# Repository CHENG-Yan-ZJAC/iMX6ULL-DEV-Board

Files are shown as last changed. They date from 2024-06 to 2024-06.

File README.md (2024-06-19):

# iMX6ULL-DEV-Board

iMX6ULL-DEV-Board is a development board based on NXP i.MX6ULL. It is composed of core board and carrier board. The boards were developed in KiCad 8.0.

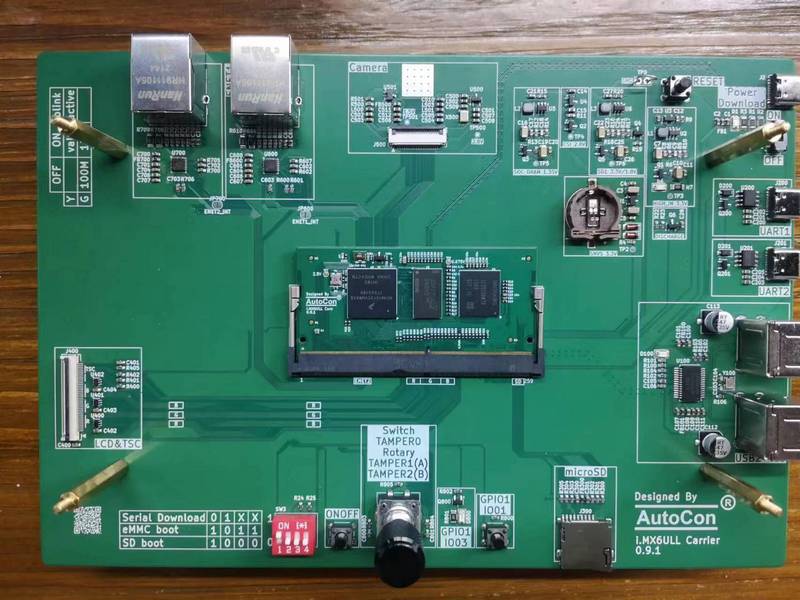
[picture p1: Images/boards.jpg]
DEV Board


## Core Board
* i.MX6ULL, MCIMX6Y2CVM08AB, ARM Cortex-A7, 798MHz.
* Samsung, KLM8G1GETF-B041, 8GB eMMC.
* Micro, MT41K256M16, DDR3L, 512MB.
* DDR4 edge connector.

## Carrier Board
* micro SD x 1, 4-bit width.
* LCD.
* CSI.
* UART1, UART2.
* USB1: used as power and flash the eMMC.
* USB2: expand to 4 USB Type-A by USB Hub (GENESYS GL850G-HHY22).
* ENET1, ENET2: PHY SMSC LAN8720A-CP-TR.
* GPIO.

## How to use
* Connect the J2 (upright corner marked "Power Download") to 5V by a Type-C line.
* Connect the Type-C (the 2nd Type-C connector marked "UART1") to PC, it is the console.
* Insert micro SD to slot (downright corner marked "micro SD").
* Set the code switch to 1 0 0 0, boot from micro SD.
* Swith on (upright corner marked "ON OFF").

## Contact:
Feel free to contact me yan.cheng@hnautocontrol.com.

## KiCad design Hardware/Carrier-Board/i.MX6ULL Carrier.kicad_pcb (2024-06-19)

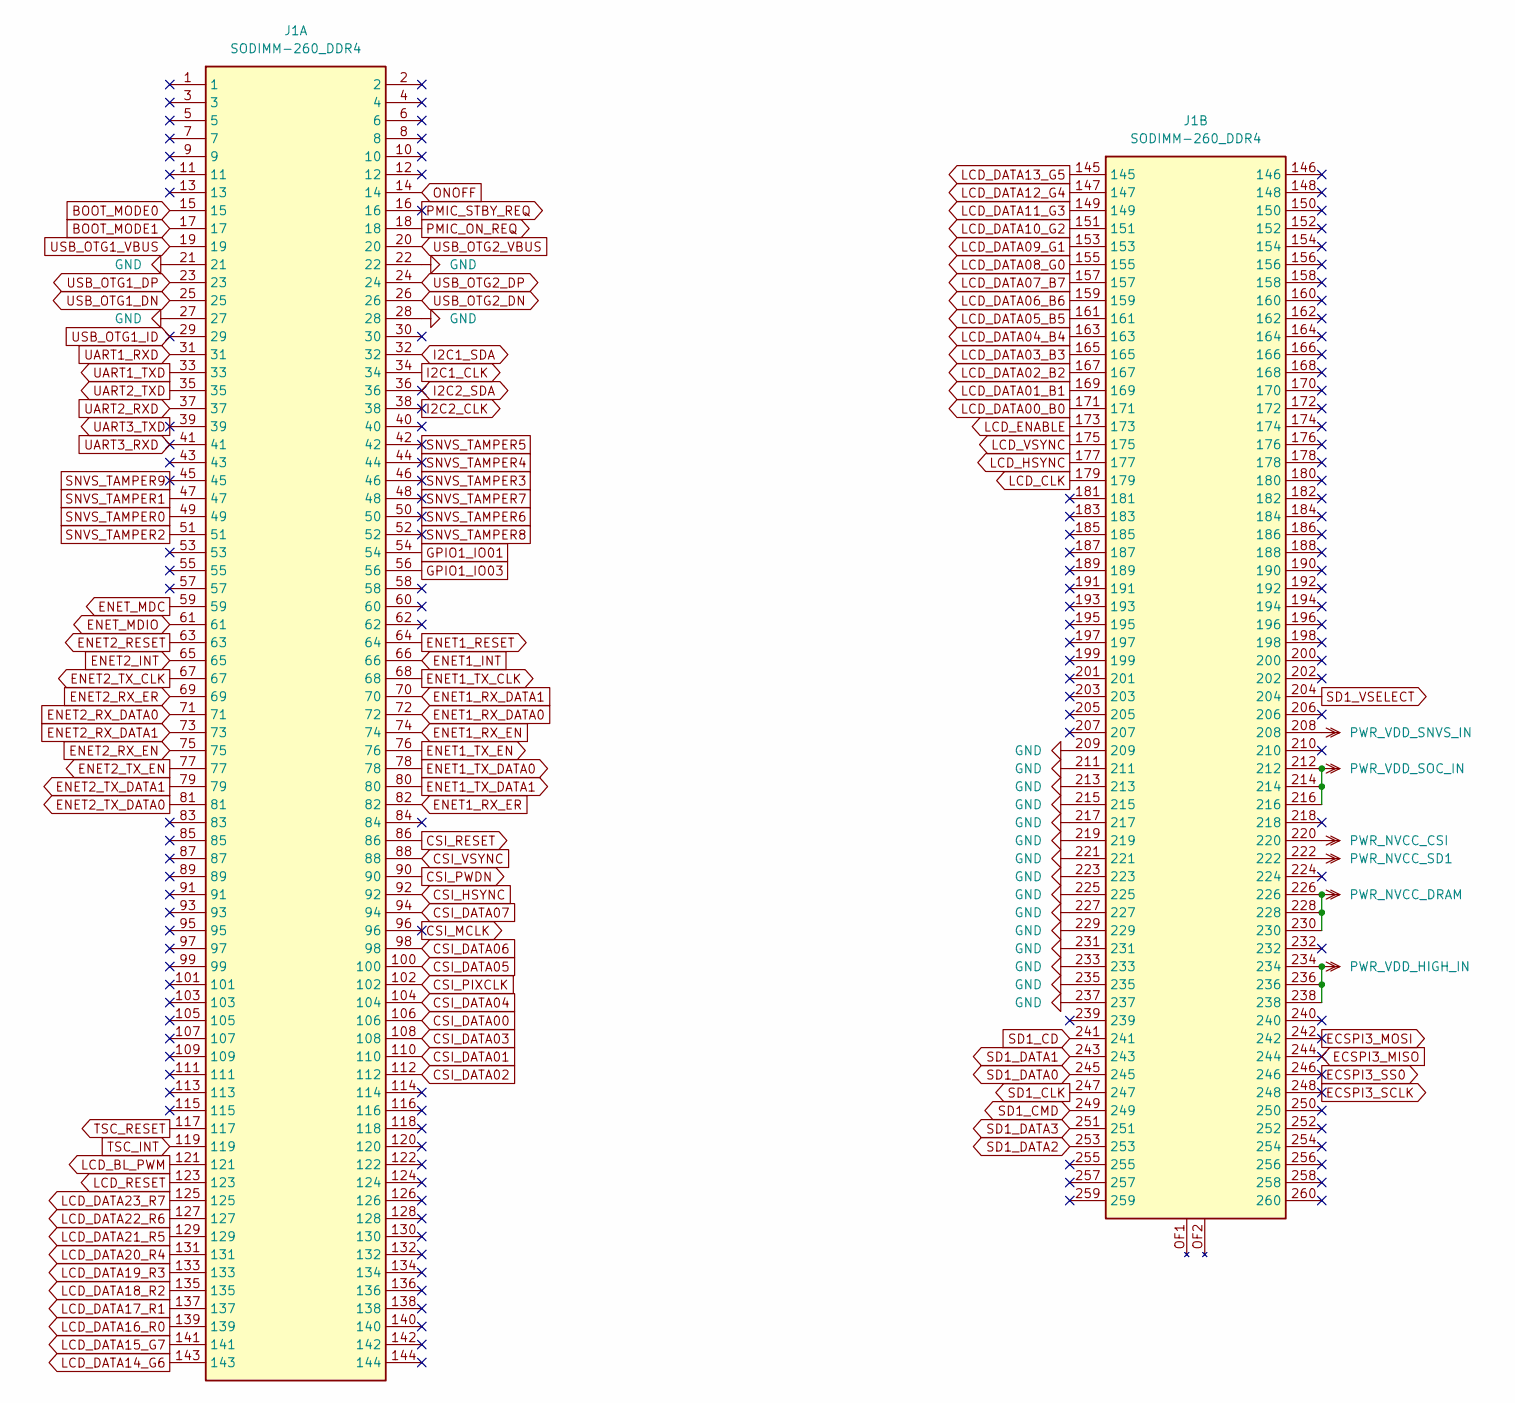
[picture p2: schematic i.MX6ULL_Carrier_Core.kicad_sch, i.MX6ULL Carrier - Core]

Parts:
J1: SODIMM-260_DDR4; SODIMM-260_DDR4_Card_slot

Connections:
BOOT_MODE0: J1.15; also elsewhere on the board
BOOT_MODE1: J1.17; also elsewhere on the board
CSI_DATA00: J1.106; also elsewhere on the board
CSI_DATA01: J1.110; also elsewhere on the board
CSI_DATA02: J1.112; also elsewhere on the board
CSI_DATA03: J1.108; also elsewhere on the board
CSI_DATA04: J1.104; also elsewhere on the board
CSI_DATA05: J1.100; also elsewhere on the board
CSI_DATA06: J1.98; also elsewhere on the board
CSI_DATA07: J1.94; also elsewhere on the board
CSI_HSYNC: J1.92; also elsewhere on the board
CSI_MCLK: J1.96
CSI_PIXCLK: J1.102; also elsewhere on the board
CSI_PWDN: J1.90; also elsewhere on the board
CSI_RESET: J1.86; also elsewhere on the board
CSI_VSYNC: J1.88; also elsewhere on the board
ECSPI3_MISO: J1.244
ECSPI3_MOSI: J1.242
ECSPI3_SCLK: J1.248
ECSPI3_SS0: J1.246
ENET1_INT: J1.66; also elsewhere on the board
ENET1_RESET: J1.64; also elsewhere on the board
ENET1_RX_DATA0: J1.72; also elsewhere on the board
ENET1_RX_DATA1: J1.70; also elsewhere on the board
ENET1_RX_EN: J1.74; also elsewhere on the board
ENET1_RX_ER: J1.82; also elsewhere on the board
ENET1_TX_CLK: J1.68; also elsewhere on the board
ENET1_TX_DATA0: J1.78; also elsewhere on the board
ENET1_TX_DATA1: J1.80; also elsewhere on the board
ENET1_TX_EN: J1.76; also elsewhere on the board
ENET2_INT: J1.65; also elsewhere on the board
ENET2_RESET: J1.63; also elsewhere on the board
ENET2_RX_DATA0: J1.71; also elsewhere on the board
ENET2_RX_DATA1: J1.73; also elsewhere on the board
ENET2_RX_EN: J1.75; also elsewhere on the board
ENET2_RX_ER: J1.69; also elsewhere on the board
ENET2_TX_CLK: J1.67; also elsewhere on the board
ENET2_TX_DATA0: J1.81; also elsewhere on the board
ENET2_TX_DATA1: J1.79; also elsewhere on the board
ENET2_TX_EN: J1.77; also elsewhere on the board
ENET_MDC: J1.59; also elsewhere on the board
ENET_MDIO: J1.61; also elsewhere on the board
GND: J1.21, J1.22, J1.27, J1.28, J1.209, J1.211, J1.213, J1.215, J1.217, J1.219, J1.221, J1.223, J1.225, J1.227, J1.229, J1.231, J1.233, J1.235, J1.237; also elsewhere on the board
GPIO1_IO01: J1.54; also elsewhere on the board
GPIO1_IO03: J1.56; also elsewhere on the board
I2C1_CLK: J1.34; also elsewhere on the board
I2C1_SDA: J1.32; also elsewhere on the board
I2C2_CLK: J1.38
I2C2_SDA: J1.36
LCD_BL_PWM: J1.121; also elsewhere on the board
LCD_CLK: J1.179; also elsewhere on the board
LCD_DATA00_B0: J1.171; also elsewhere on the board
LCD_DATA01_B1: J1.169; also elsewhere on the board
LCD_DATA02_B2: J1.167; also elsewhere on the board
LCD_DATA03_B3: J1.165; also elsewhere on the board
LCD_DATA04_B4: J1.163; also elsewhere on the board
LCD_DATA05_B5: J1.161; also elsewhere on the board
LCD_DATA06_B6: J1.159; also elsewhere on the board
LCD_DATA07_B7: J1.157; also elsewhere on the board
LCD_DATA08_G0: J1.155; also elsewhere on the board
LCD_DATA09_G1: J1.153; also elsewhere on the board
LCD_DATA10_G2: J1.151; also elsewhere on the board
LCD_DATA11_G3: J1.149; also elsewhere on the board
LCD_DATA12_G4: J1.147; also elsewhere on the board
LCD_DATA13_G5: J1.145; also elsewhere on the board
LCD_DATA14_G6: J1.143; also elsewhere on the board
LCD_DATA15_G7: J1.141; also elsewhere on the board
LCD_DATA16_R0: J1.139; also elsewhere on the board
LCD_DATA17_R1: J1.137; also elsewhere on the board
LCD_DATA18_R2: J1.135; also elsewhere on the board
LCD_DATA19_R3: J1.133; also elsewhere on the board
LCD_DATA20_R4: J1.131; also elsewhere on the board
LCD_DATA21_R5: J1.129; also elsewhere on the board
LCD_DATA22_R6: J1.127; also elsewhere on the board
LCD_DATA23_R7: J1.125; also elsewhere on the board
LCD_ENABLE: J1.173; also elsewhere on the board
LCD_HSYNC: J1.177; also elsewhere on the board
LCD_RESET: J1.123; also elsewhere on the board
LCD_VSYNC: J1.175; also elsewhere on the board
ONOFF: J1.14; also elsewhere on the board
PMIC_ON_REQ: J1.18; also elsewhere on the board
PMIC_STBY_REQ: J1.16
PWR_NVCC_CSI: J1.220; also elsewhere on the board
PWR_NVCC_DRAM: J1.212, J1.214, J1.216, J1.226, J1.228, J1.230; also elsewhere on the board
PWR_NVCC_SD1: J1.222; also elsewhere on the board
PWR_VDD_HIGH_IN: J1.234, J1.236, J1.238; also elsewhere on the board
PWR_VDD_SNVS_IN: J1.208; also elsewhere on the board
SD1_CD: J1.241; also elsewhere on the board
SD1_CLK: J1.247; also elsewhere on the board
SD1_CMD: J1.249; also elsewhere on the board
SD1_DATA0: J1.245; also elsewhere on the board
SD1_DATA1: J1.243; also elsewhere on the board
SD1_DATA2: J1.253; also elsewhere on the board
SD1_DATA3: J1.251; also elsewhere on the board
SD1_VSELECT: J1.204; also elsewhere on the board
SNVS_TAMPER0: J1.49; also elsewhere on the board
SNVS_TAMPER1: J1.47; also elsewhere on the board
SNVS_TAMPER2: J1.51; also elsewhere on the board
SNVS_TAMPER3: J1.46
SNVS_TAMPER4: J1.44
SNVS_TAMPER5: J1.42
SNVS_TAMPER6: J1.50
SNVS_TAMPER7: J1.48
SNVS_TAMPER8: J1.52
SNVS_TAMPER9: J1.45
TSC_INT: J1.119; also elsewhere on the board
TSC_RESET: J1.117; also elsewhere on the board
UART1_RXD: J1.31; also elsewhere on the board
UART1_TXD: J1.33; also elsewhere on the board
UART2_RXD: J1.37; also elsewhere on the board
UART2_TXD: J1.35; also elsewhere on the board
UART3_RXD: J1.41
UART3_TXD: J1.39
USB_OTG1_DN: J1.25; also elsewhere on the board
USB_OTG1_DP: J1.23; also elsewhere on the board
USB_OTG1_ID: J1.29
USB_OTG1_VBUS: J1.19; also elsewhere on the board
USB_OTG2_DN: J1.26; also elsewhere on the board
USB_OTG2_DP: J1.24; also elsewhere on the board
USB_OTG2_VBUS: J1.20; also elsewhere on the board

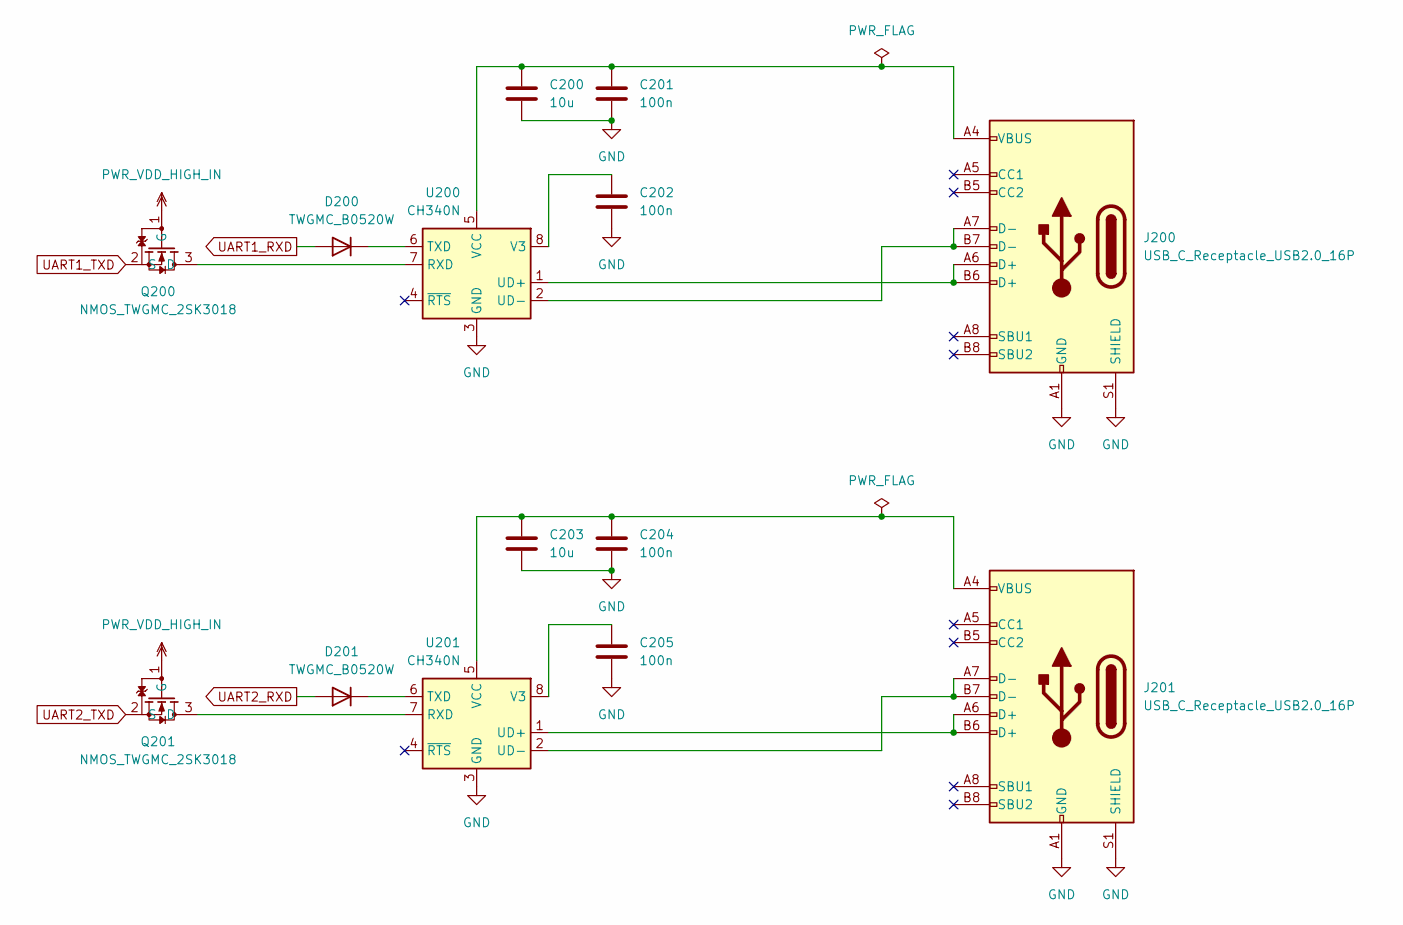
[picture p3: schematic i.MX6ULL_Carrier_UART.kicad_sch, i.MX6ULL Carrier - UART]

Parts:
C200, C203: 10u; C_0603_1608Metric
C201, C202, C204, C205: 100n; C_0603_1608Metric
D200, D201: TWGMC_B0520W; D_SOD-123
J200, J201: USB_C_Receptacle_USB2.0_16P; USB_C_Receptacle_G-Switch_GT-USB-7010ASV
Q200, Q201: NMOS_TWGMC_2SK3018; SOT-23-3
U200, U201: CH340N; SOP-8_3.9x4.9mm_P1.27mm

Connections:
GND: C200.2, C201.2, C202.2, C203.2, C204.2, C205.2, J200.A1 (GND), J200.A12 (GND), J200.B1 (GND), J200.B12 (GND), J200.S1 (SHIELD), J201.A1 (GND), J201.A12 (GND), J201.B1 (GND), J201.B12 (GND), J201.S1 (SHIELD), U200.3 (GND), U201.3 (GND); also elsewhere on the board
unnamed: D200.1 (K), U200.6 (TXD)
unnamed: D201.1 (K), U201.6 (TXD)
unnamed: Q200.3 (D), U200.7 (RXD)
unnamed: Q201.3 (D), U201.7 (RXD)
unnamed: J200.A6 (D+), J200.B6 (D+), U200.1 (UD+)
unnamed: J200.A7 (D-), J200.B7 (D-), U200.2 (UD-)
unnamed: C202.1, U200.8 (V3)
unnamed: C200.1, C201.1, J200.A4 (VBUS), J200.A9 (VBUS), J200.B4 (VBUS), J200.B9 (VBUS), U200.5 (VCC)
unnamed: J201.A6 (D+), J201.B6 (D+), U201.1 (UD+)
unnamed: J201.A7 (D-), J201.B7 (D-), U201.2 (UD-)
unnamed: C205.1, U201.8 (V3)
unnamed: C203.1, C204.1, J201.A4 (VBUS), J201.A9 (VBUS), J201.B4 (VBUS), J201.B9 (VBUS), U201.5 (VCC)
PWR_VDD_HIGH_IN: Q200.1 (G), Q201.1 (G); also elsewhere on the board
UART1_RXD: D200.2 (A); also elsewhere on the board
UART1_TXD: Q200.2 (S); also elsewhere on the board
UART2_RXD: D201.2 (A); also elsewhere on the board
UART2_TXD: Q201.2 (S); also elsewhere on the board

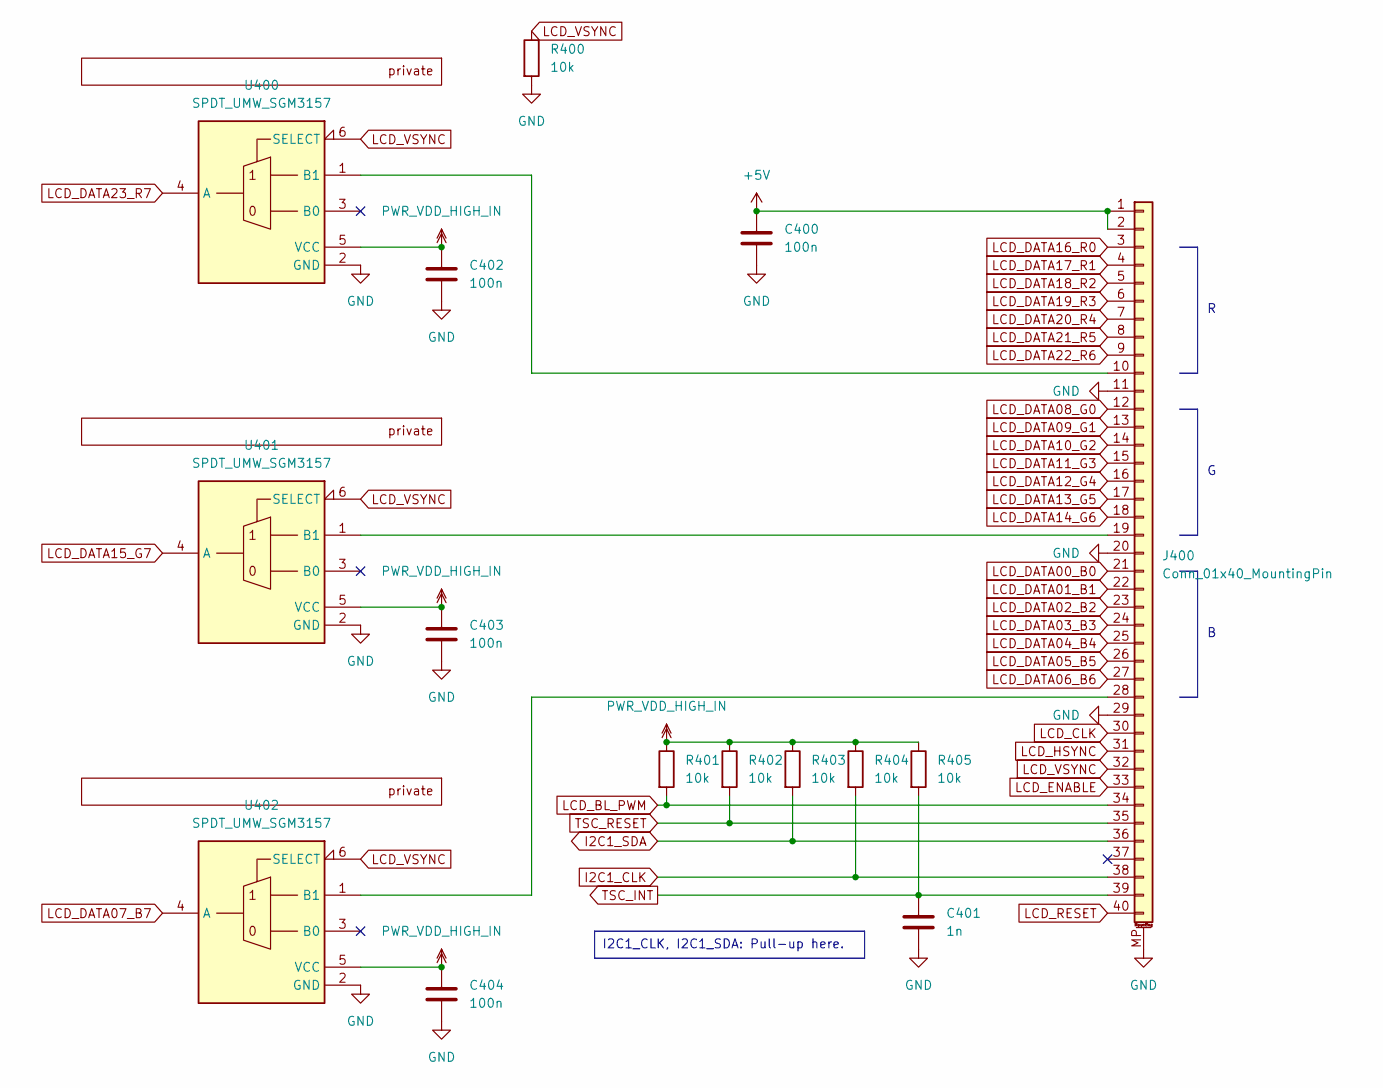
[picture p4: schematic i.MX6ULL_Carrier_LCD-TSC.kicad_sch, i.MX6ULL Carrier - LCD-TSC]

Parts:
C400, C402, C403, C404: 100n; C_0603_1608Metric
C401: 1n; C_0603_1608Metric
J400: Conn_01x40_MountingPin; Connector_FPC_1x40-1MP_P0.05mm
R400, R401, R402, R403, R404, R405: 10k; R_0603_1608Metric
U400, U401, U402: SPDT_UMW_SGM3157; SOT-363_SC-70-6

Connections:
+5V: C400.1, J400.1, J400.2; also elsewhere on the board
GND: C400.2, C401.2, C402.2, C403.2, C404.2, J400.11, J400.20, J400.29, J400.MP (MountPin), R400.2, U400.2 (GND), U401.2 (GND), U402.2 (GND); also elsewhere on the board
I2C1_CLK: J400.38, R404.2; also elsewhere on the board
I2C1_SDA: J400.36, R403.2; also elsewhere on the board
LCD_BL_PWM: J400.34, R401.2; also elsewhere on the board
LCD_CLK: J400.30; also elsewhere on the board
LCD_DATA00_B0: J400.21; also elsewhere on the board
LCD_DATA01_B1: J400.22; also elsewhere on the board
LCD_DATA02_B2: J400.23; also elsewhere on the board
LCD_DATA03_B3: J400.24; also elsewhere on the board
LCD_DATA04_B4: J400.25; also elsewhere on the board
LCD_DATA05_B5: J400.26; also elsewhere on the board
LCD_DATA06_B6: J400.27; also elsewhere on the board
LCD_DATA07_B7: U402.4 (A); also elsewhere on the board
LCD_DATA08_G0: J400.12; also elsewhere on the board
LCD_DATA09_G1: J400.13; also elsewhere on the board
LCD_DATA10_G2: J400.14; also elsewhere on the board
LCD_DATA11_G3: J400.15; also elsewhere on the board
LCD_DATA12_G4: J400.16; also elsewhere on the board
LCD_DATA13_G5: J400.17; also elsewhere on the board
LCD_DATA14_G6: J400.18; also elsewhere on the board
LCD_DATA15_G7: U401.4 (A); also elsewhere on the board
LCD_DATA16_R0: J400.3; also elsewhere on the board
LCD_DATA17_R1: J400.4; also elsewhere on the board
LCD_DATA18_R2: J400.5; also elsewhere on the board
LCD_DATA19_R3: J400.6; also elsewhere on the board
LCD_DATA20_R4: J400.7; also elsewhere on the board
LCD_DATA21_R5: J400.8; also elsewhere on the board
LCD_DATA22_R6: J400.9; also elsewhere on the board
LCD_DATA23_R7: U400.4 (A); also elsewhere on the board
LCD_ENABLE: J400.33; also elsewhere on the board
LCD_HSYNC: J400.31; also elsewhere on the board
LCD_RESET: J400.40; also elsewhere on the board
LCD_VSYNC: J400.32, R400.1, U400.6 (SELECT), U401.6 (SELECT), U402.6 (SELECT); also elsewhere on the board
unnamed: J400.10, U400.1 (B1)
unnamed: J400.19, U401.1 (B1)
unnamed: J400.28, U402.1 (B1)
PWR_VDD_HIGH_IN: C402.1, C403.1, C404.1, R401.1, R402.1, R403.1, R404.1, R405.1, U400.5 (VCC), U401.5 (VCC), U402.5 (VCC); also elsewhere on the board
TSC_INT: C401.1, J400.39, R405.2; also elsewhere on the board
TSC_RESET: J400.35, R402.2; also elsewhere on the board

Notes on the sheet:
I2C1_CLK, I2C1_SDA: Pull-up here.

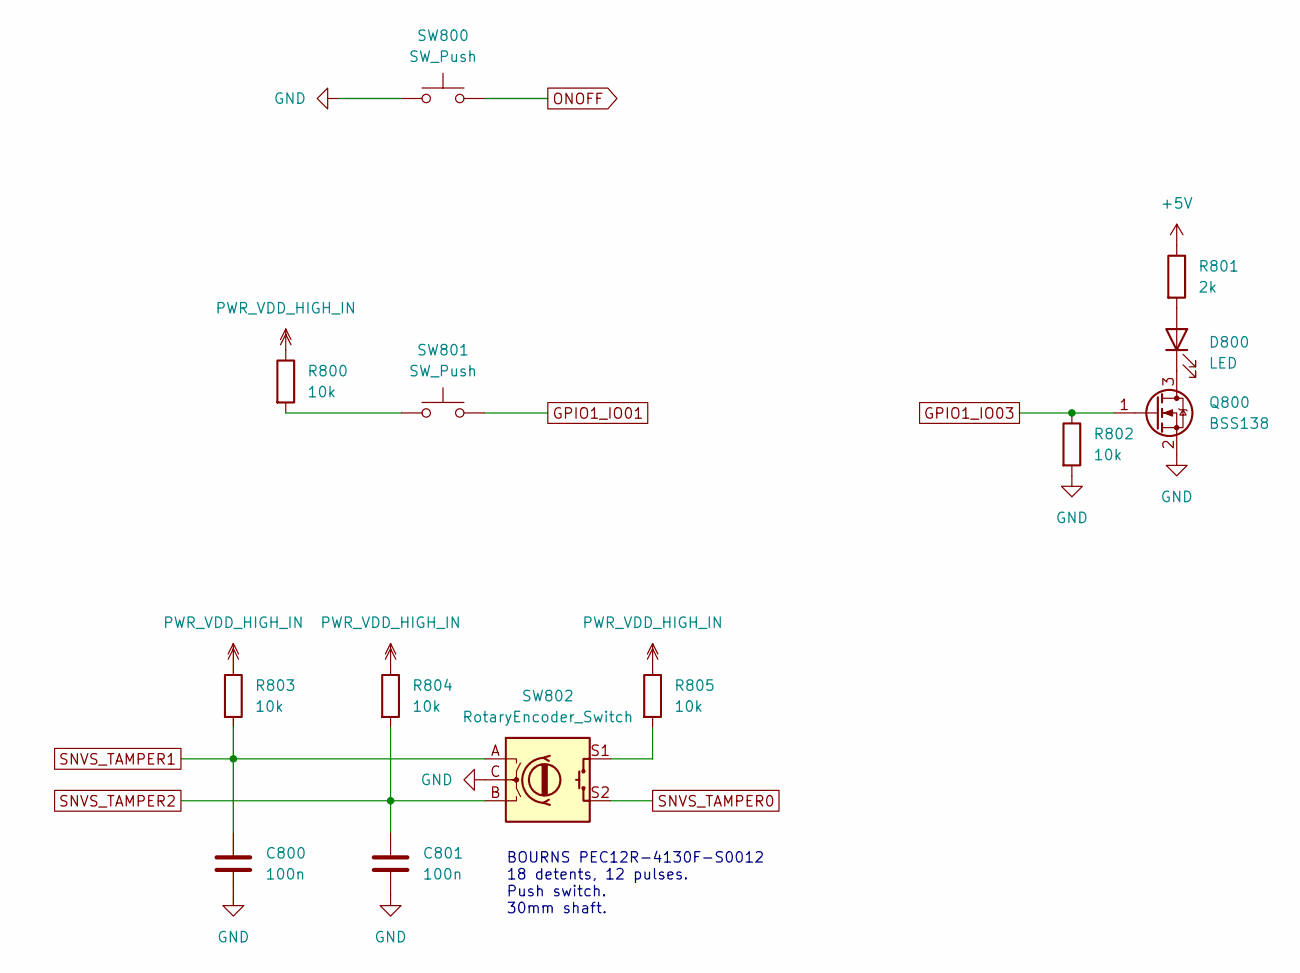
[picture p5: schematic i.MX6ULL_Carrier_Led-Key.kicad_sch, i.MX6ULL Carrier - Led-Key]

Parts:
C800, C801: 100n; C_0603_1608Metric
D800: LED; LED_1206_3216Metric
Q800: BSS138; SOT-23-3
R800, R802, R803, R804, R805: 10k; R_0603_1608Metric
R801: 2k; R_1206_3216Metric
SW800, SW801: SW_Push; SW_PUSH_6mm
SW802: RotaryEncoder_Switch; RotaryEncoder_Bourns_Vertical_PEC12R-3x17F-Sxxxx

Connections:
+5V: R801.1; also elsewhere on the board
GND: C800.2, C801.2, Q800.2 (S), R802.2, SW800.1, SW802.C; also elsewhere on the board
GPIO1_IO01: SW801.2; also elsewhere on the board
GPIO1_IO03: Q800.1 (G), R802.1; also elsewhere on the board
unnamed: D800.2 (A), R801.2
unnamed: D800.1 (K), Q800.3 (D)
unnamed: R800.2, SW801.1
unnamed: R805.2, SW802.S1
ONOFF: SW800.2; also elsewhere on the board
PWR_VDD_HIGH_IN: R800.1, R803.1, R804.1, R805.1; also elsewhere on the board
SNVS_TAMPER0: SW802.S2; also elsewhere on the board
SNVS_TAMPER1: C800.1, R803.2, SW802.A; also elsewhere on the board
SNVS_TAMPER2: C801.1, R804.2, SW802.B; also elsewhere on the board

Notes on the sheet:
BOURNS PEC12R-4130F-S0012 18 detents, 12 pulses. Push switch. 30mm shaft.

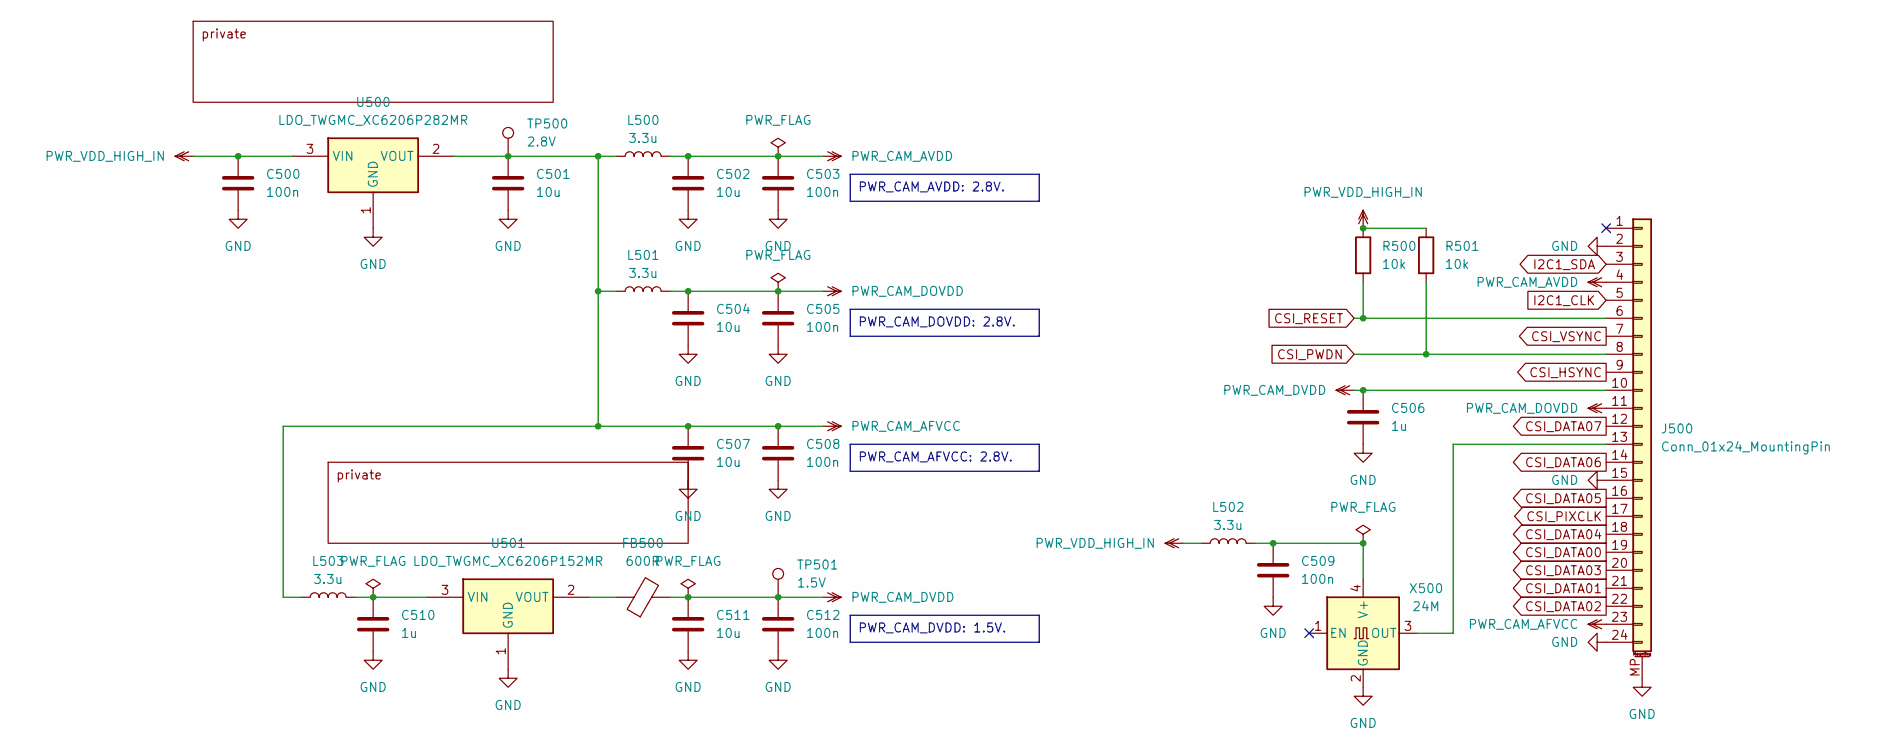
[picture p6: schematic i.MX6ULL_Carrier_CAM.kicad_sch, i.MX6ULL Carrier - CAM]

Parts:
C500, C503, C505, C508, C509, C512: 100n; C_0603_1608Metric
C501, C502, C504, C507, C511: 10u; C_0603_1608Metric
C506, C510: 1u; C_0603_1608Metric
FB500: 600R; L_0603_1608Metric
J500: Conn_01x24_MountingPin; Connector_FPC_1x24-1MP_P0.05mm
L500, L501, L502, L503: 3.3u; L_0603_1608Metric
R500, R501: 10k; R_0603_1608Metric
TP500: 2.8V; TestPoint_Pad_D1.0mm
TP501: 1.5V; TestPoint_Pad_D1.0mm
U500: LDO_TWGMC_XC6206P282MR; SOT-23-3
U501: LDO_TWGMC_XC6206P152MR; SOT-23-3
X500: 24M; Oscillator_SMD_EuroQuartz_XO32-4Pin_3.2x2.5mm

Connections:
CSI_DATA00: J500.19; also elsewhere on the board
CSI_DATA01: J500.21; also elsewhere on the board
CSI_DATA02: J500.22; also elsewhere on the board
CSI_DATA03: J500.20; also elsewhere on the board
CSI_DATA04: J500.18; also elsewhere on the board
CSI_DATA05: J500.16; also elsewhere on the board
CSI_DATA06: J500.14; also elsewhere on the board
CSI_DATA07: J500.12; also elsewhere on the board
CSI_HSYNC: J500.9; also elsewhere on the board
CSI_PIXCLK: J500.17; also elsewhere on the board
CSI_PWDN: J500.8, R501.2; also elsewhere on the board
CSI_RESET: J500.6, R500.2; also elsewhere on the board
CSI_VSYNC: J500.7; also elsewhere on the board
GND: C500.2, C501.2, C502.2, C503.2, C504.2, C505.2, C506.2, C507.2, C508.2, C509.2, C510.2, C511.2, C512.2, J500.2, J500.15, J500.24, J500.MP (MountPin), U500.1 (GND), U501.1 (GND), X500.2 (GND); also elsewhere on the board
I2C1_CLK: J500.5; also elsewhere on the board
I2C1_SDA: J500.3; also elsewhere on the board
unnamed: J500.13, X500.3 (OUT)
unnamed: C510.1, L503.2, U501.3 (VIN)
unnamed: FB500.1, U501.2 (VOUT)
unnamed: C509.1, L502.2, X500.4 (V+)
PWR_CAM_AFVCC: C501.1, C507.1, C508.1, J500.23, L500.1, L501.1, L503.1, TP500.1, U500.2 (VOUT)
PWR_CAM_AVDD: C502.1, C503.1, J500.4, L500.2
PWR_CAM_DOVDD: C504.1, C505.1, J500.11, L501.2
PWR_CAM_DVDD: C506.1, C511.1, C512.1, FB500.2, J500.10, TP501.1
PWR_VDD_HIGH_IN: C500.1, L502.1, R500.1, R501.1, U500.3 (VIN); also elsewhere on the board

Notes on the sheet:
PWR_CAM_DVDD: 1.5V.
PWR_CAM_AFVCC: 2.8V.
PWR_CAM_AVDD: 2.8V.
PWR_CAM_DOVDD: 2.8V.

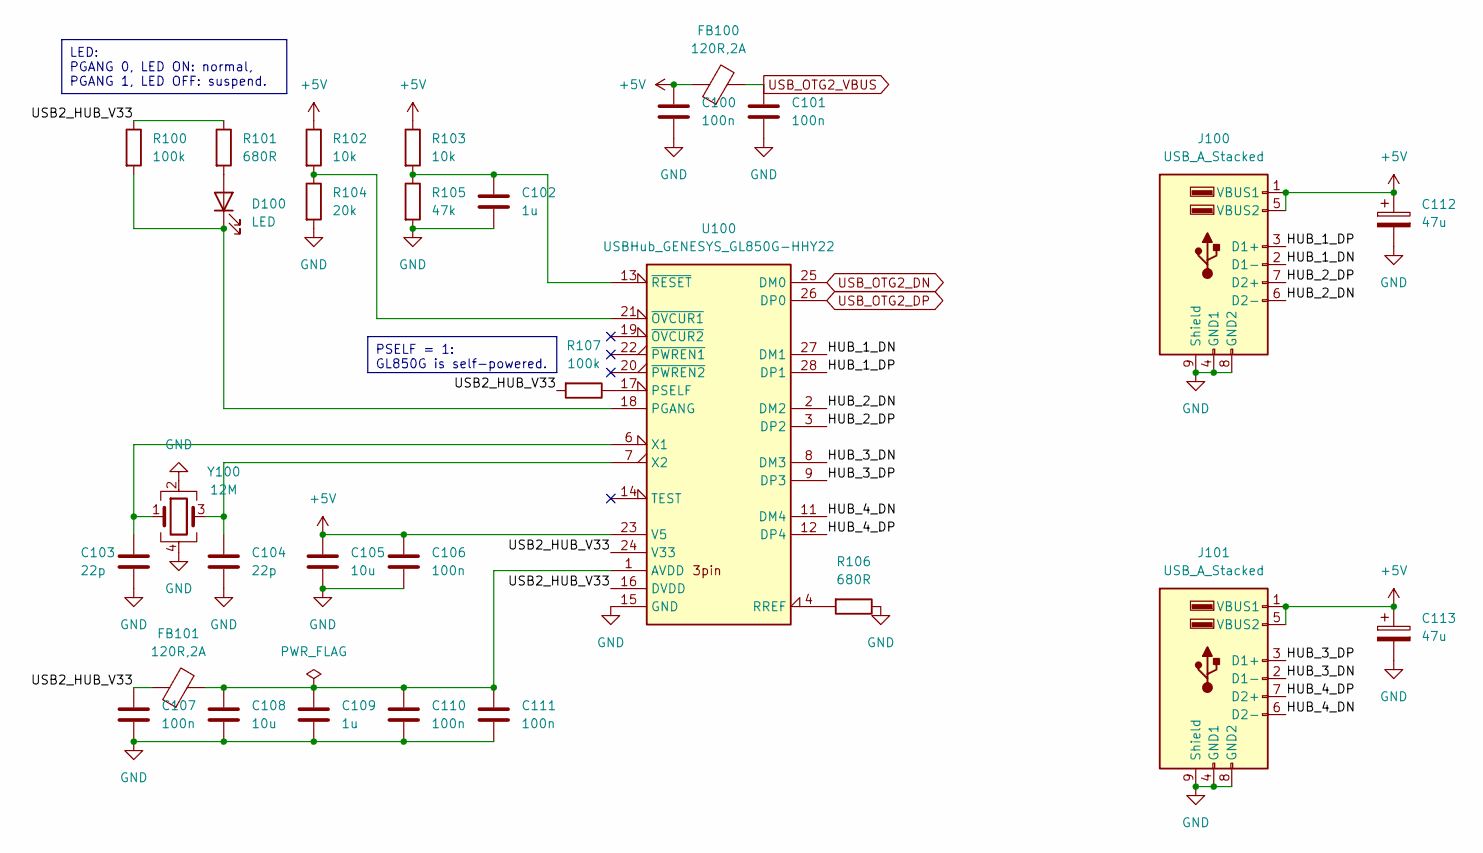
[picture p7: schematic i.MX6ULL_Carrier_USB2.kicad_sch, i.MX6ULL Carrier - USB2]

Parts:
C100, C101, C106, C107, C110, C111: 100n; C_0603_1608Metric
C102, C109: 1u; C_0603_1608Metric
C103, C104: 22p; C_0603_1608Metric
C105, C108: 10u; C_0603_1608Metric
C112, C113: 47u; CP_Elec_6.3x5.4
D100: LED; LED_1206_3216Metric
FB100, FB101: 120R,2A; L_0603_1608Metric
J100, J101: USB_A_Stacked; USB_A_CUI_UJ2-ADH-TH_Horizontal_Stacked
R100, R107: 100k; R_0603_1608Metric
R101, R106: 680R; R_0603_1608Metric
R102, R103: 10k; R_0603_1608Metric
R104: 20k; R_0603_1608Metric
R105: 47k; R_0603_1608Metric
U100: USBHub_GENESYS_GL850G-HHY22; SSOP-28_5.3x10.2mm_P0.65mm
Y100: 12M; Crystal_SMD_3225-4Pin_3.2x2.5mm

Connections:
+5V: C100.1, C105.1, C106.1, C112.1, C113.1, FB100.1, J100.1 (VBUS1), J100.5 (VBUS2), J101.1 (VBUS1), J101.5 (VBUS2), R102.1, R103.1, U100.23 (V5); also elsewhere on the board
/USB2/HUB_1_DN: J100.2 (D1-), U100.27 (DM1)
/USB2/HUB_1_DP: J100.3 (D1+), U100.28 (DP1)
/USB2/HUB_2_DN: J100.6 (D2-), U100.2 (DM2)
/USB2/HUB_2_DP: J100.7 (D2+), U100.3 (DP2)
/USB2/HUB_3_DN: J101.2 (D1-), U100.8 (DM3)
/USB2/HUB_3_DP: J101.3 (D1+), U100.9 (DP3)
/USB2/HUB_4_DN: J101.6 (D2-), U100.11 (DM4)
/USB2/HUB_4_DP: J101.7 (D2+), U100.12 (DP4)
/USB2/USB2_HUB_V33: C107.1, FB101.1, R100.1, R101.1, R107.2, U100.16 (DVDD), U100.24 (V33)
GND: C100.2, C101.2, C102.2, C103.2, C104.2, C105.2, C106.2, C107.2, C108.2, C109.2, C110.2, C111.2, C112.2, C113.2, J100.4 (GND1), J100.8 (GND2), J100.9 (Shield), J101.4 (GND1), J101.8 (GND2), J101.9 (Shield), R104.2, R105.2, R106.1, U100.15 (GND), Y100.2, Y100.4; also elsewhere on the board
unnamed: C108.1, C109.1, C110.1, C111.1, FB101.2, U100.1 (AVDD), U100.5 (AVDD), U100.10 (AVDD)
unnamed: D100.2 (A), R101.2
unnamed: D100.1 (K), R100.2, U100.18 (PGANG)
unnamed: R107.1, U100.17 (PSELF)
unnamed: R106.2, U100.4 (RREF)
unnamed: C103.1, U100.6 (X1), Y100.1
unnamed: C104.1, U100.7 (X2), Y100.3
unnamed: R102.2, R104.1, U100.21 (~OVCUR1)
unnamed: C102.1, R103.2, R105.1, U100.13 (~RESET)
USB_OTG2_DN: U100.25 (DM0); also elsewhere on the board
USB_OTG2_DP: U100.26 (DP0); also elsewhere on the board
USB_OTG2_VBUS: C101.1, FB100.2; also elsewhere on the board

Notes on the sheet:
PSELF = 1: GL850G is self-powered.
LED: PGANG 0, LED ON: normal, PGANG 1, LED OFF: suspend.

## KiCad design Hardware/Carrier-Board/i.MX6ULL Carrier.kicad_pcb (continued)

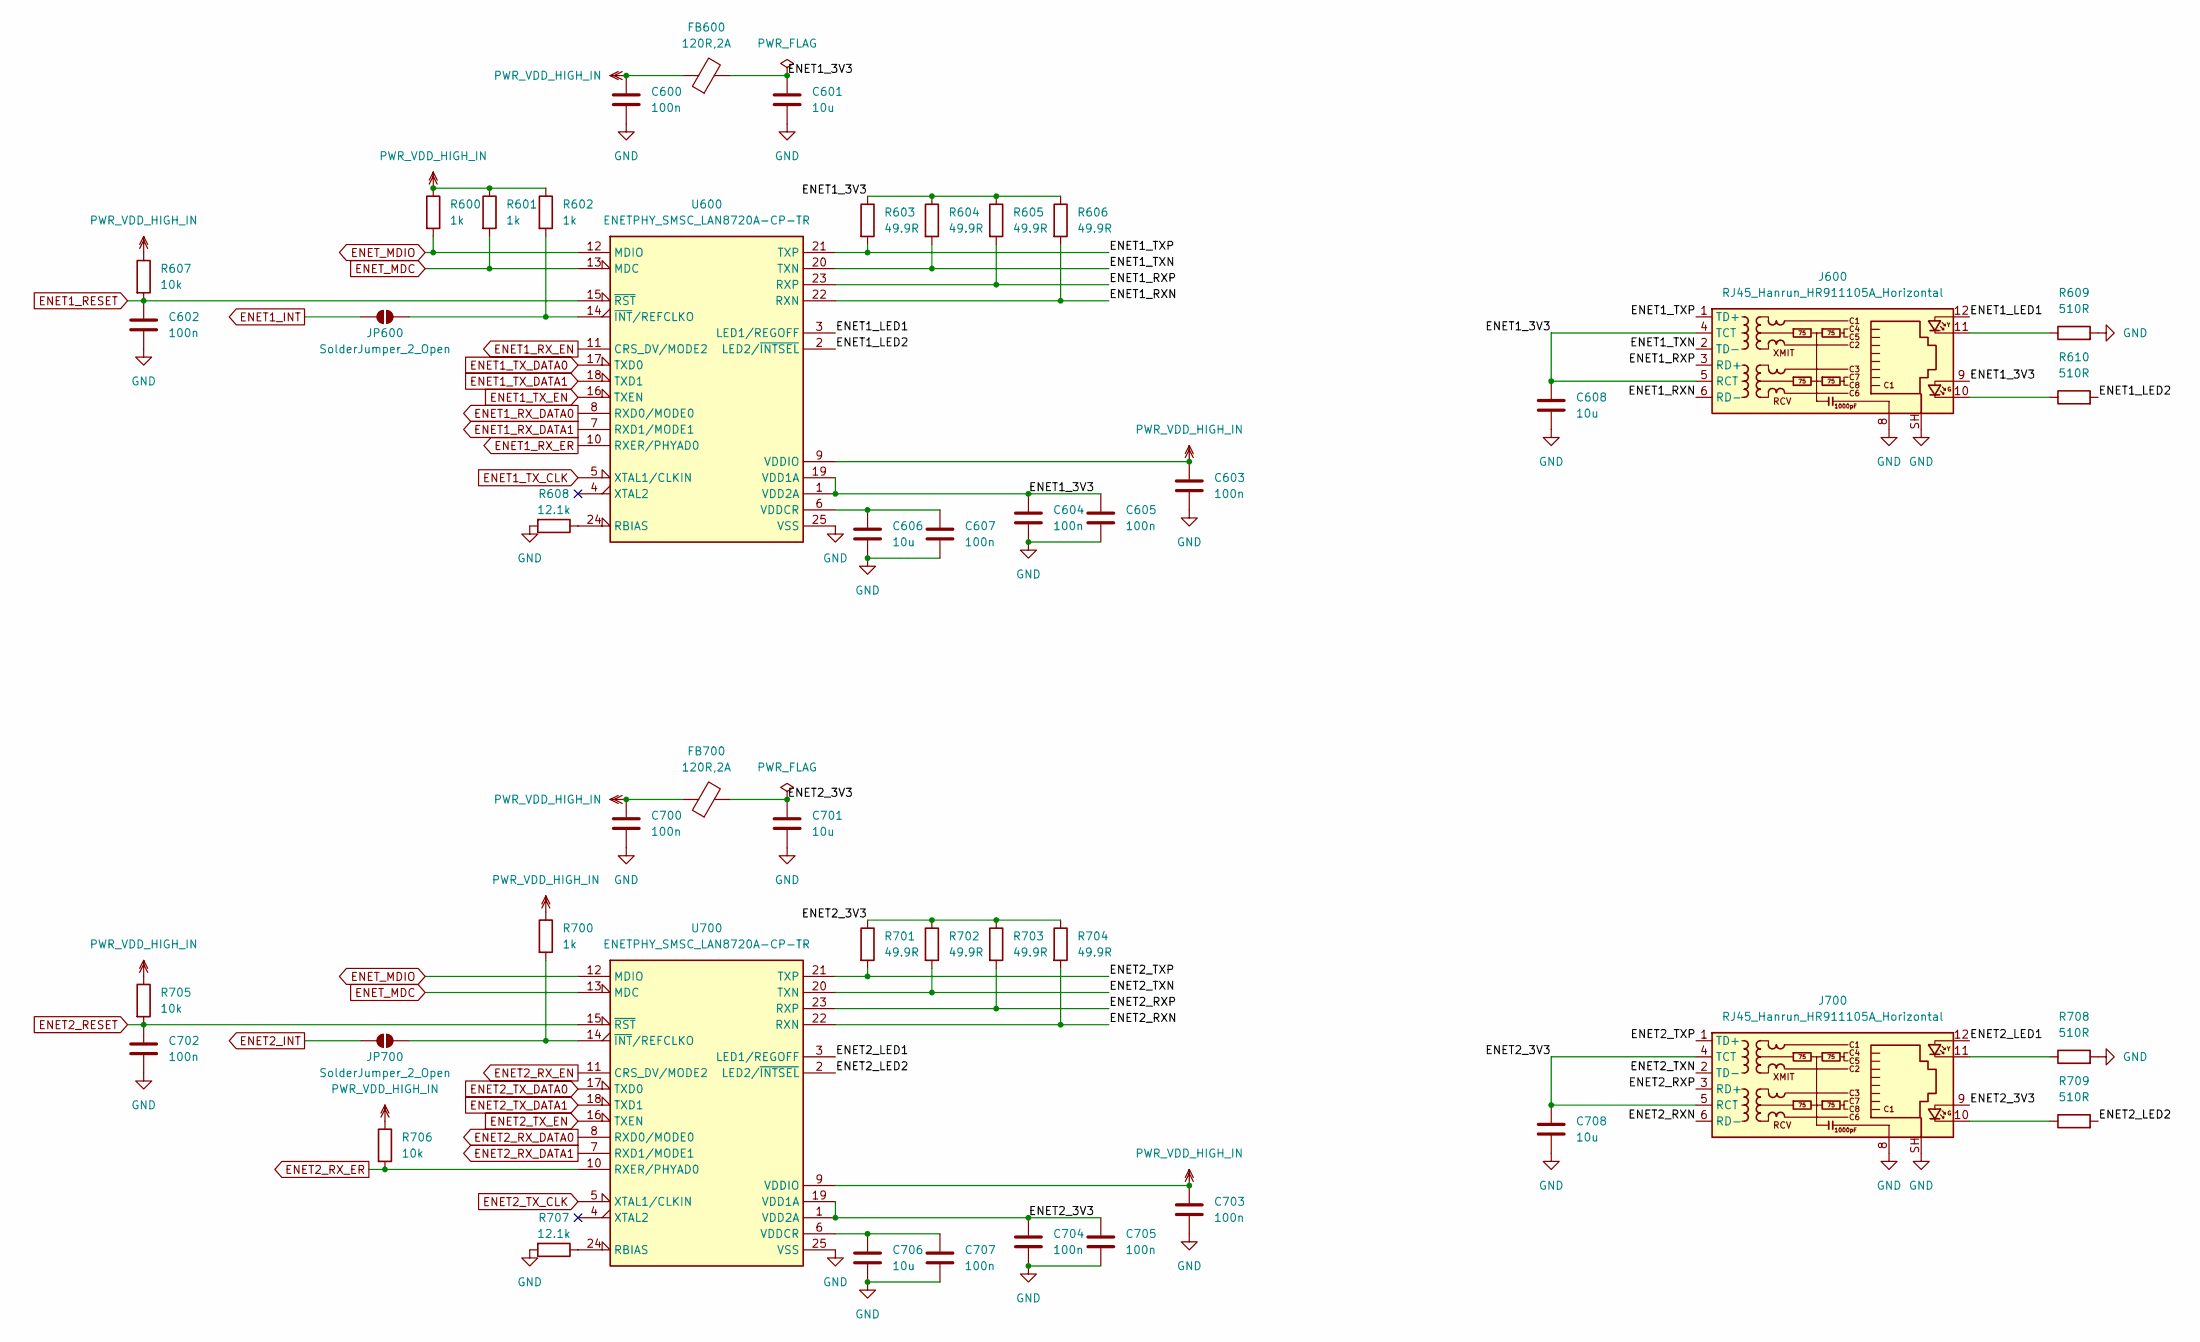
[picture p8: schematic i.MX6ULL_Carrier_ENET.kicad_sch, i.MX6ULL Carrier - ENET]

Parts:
C600, C602, C603, C604, C605, C607, C700, C702, C703, C704, C705, C707: 100n; C_0603_1608Metric
C601, C606, C608, C701, C706, C708: 10u; C_0603_1608Metric
FB600, FB700: 120R,2A; L_0603_1608Metric
J600, J700: RJ45_Hanrun_HR911105A_Horizontal
JP600, JP700: SolderJumper_2_Open; SolderJumper-2_P1.3mm_Open_RoundedPad1.0x1.5mm
R600, R601, R602, R700: 1k; R_0603_1608Metric
R603, R604, R605, R606, R701, R702, R703, R704: 49.9R; R_0603_1608Metric
R607, R705, R706: 10k; R_0603_1608Metric
R608, R707: 12.1k; R_0603_1608Metric
R609, R610, R708, R709: 510R; R_1206_3216Metric
U600, U700: ENETPHY_SMSC_LAN8720A-CP-TR; QFN-24-1EP_4x4mm_P0.5mm_EP2.5x2.5mm

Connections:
/ENET/ENET1_3V3: C601.1, C604.1, C605.1, C608.1, FB600.2, J600.4 (TCT), J600.5 (RCT), J600.9, R603.1, R604.1, R605.1, R606.1, U600.1 (VDD2A), U600.19 (VDD1A)
/ENET/ENET1_LED1: J600.12, U600.3 (LED1/REGOFF)
/ENET/ENET1_LED2: R610.2, U600.2 (LED2/~INTSEL)
/ENET/ENET1_RXN: J600.6 (RD-), R606.2, U600.22 (RXN)
/ENET/ENET1_RXP: J600.3 (RD+), R605.2, U600.23 (RXP)
/ENET/ENET1_TXN: J600.2 (TD-), R604.2, U600.20 (TXN)
/ENET/ENET1_TXP: J600.1 (TD+), R603.2, U600.21 (TXP)
/ENET/ENET2_3V3: C701.1, C704.1, C705.1, C708.1, FB700.2, J700.4 (TCT), J700.5 (RCT), J700.9, R701.1, R702.1, R703.1, R704.1, U700.1 (VDD2A), U700.19 (VDD1A)
/ENET/ENET2_LED1: J700.12, U700.3 (LED1/REGOFF)
/ENET/ENET2_LED2: R709.2, U700.2 (LED2/~INTSEL)
/ENET/ENET2_RXN: J700.6 (RD-), R704.2, U700.22 (RXN)
/ENET/ENET2_RXP: J700.3 (RD+), R703.2, U700.23 (RXP)
/ENET/ENET2_TXN: J700.2 (TD-), R702.2, U700.20 (TXN)
/ENET/ENET2_TXP: J700.1 (TD+), R701.2, U700.21 (TXP)
ENET1_INT: JP600.1 (A); also elsewhere on the board
ENET1_RESET: C602.1, R607.2, U600.15 (~RST); also elsewhere on the board
ENET1_RX_DATA0: U600.8 (RXD0/MODE0); also elsewhere on the board
ENET1_RX_DATA1: U600.7 (RXD1/MODE1); also elsewhere on the board
ENET1_RX_EN: U600.11 (CRS_DV/MODE2); also elsewhere on the board
ENET1_RX_ER: U600.10 (RXER/PHYAD0); also elsewhere on the board
ENET1_TX_CLK: U600.5 (XTAL1/CLKIN); also elsewhere on the board
ENET1_TX_DATA0: U600.17 (TXD0); also elsewhere on the board
ENET1_TX_DATA1: U600.18 (TXD1); also elsewhere on the board
ENET1_TX_EN: U600.16 (TXEN); also elsewhere on the board
ENET2_INT: JP700.1 (A); also elsewhere on the board
ENET2_RESET: C702.1, R705.2, U700.15 (~RST); also elsewhere on the board
ENET2_RX_DATA0: U700.8 (RXD0/MODE0); also elsewhere on the board
ENET2_RX_DATA1: U700.7 (RXD1/MODE1); also elsewhere on the board
ENET2_RX_EN: U700.11 (CRS_DV/MODE2); also elsewhere on the board
ENET2_RX_ER: R706.2, U700.10 (RXER/PHYAD0); also elsewhere on the board
ENET2_TX_CLK: U700.5 (XTAL1/CLKIN); also elsewhere on the board
ENET2_TX_DATA0: U700.17 (TXD0); also elsewhere on the board
ENET2_TX_DATA1: U700.18 (TXD1); also elsewhere on the board
ENET2_TX_EN: U700.16 (TXEN); also elsewhere on the board
ENET_MDC: R601.2, U600.13 (MDC), U700.13 (MDC); also elsewhere on the board
ENET_MDIO: R600.2, U600.12 (MDIO), U700.12 (MDIO); also elsewhere on the board
GND: C600.2, C601.2, C602.2, C603.2, C604.2, C605.2, C606.2, C607.2, C608.2, C700.2, C701.2, C702.2, C703.2, C704.2, C705.2, C706.2, C707.2, C708.2, J600.8, J600.SH, J700.8, J700.SH, R608.2, R609.2, R707.2, R708.2, U600.25 (VSS), U700.25 (VSS); also elsewhere on the board
unnamed: J600.10, R610.1
unnamed: J600.11, R609.1
unnamed: J700.10, R709.1
unnamed: J700.11, R708.1
unnamed: JP600.2 (B), R602.2, U600.14 (~INT/REFCLKO)
unnamed: JP700.2 (B), R700.2, U700.14 (~INT/REFCLKO)
unnamed: R608.1, U600.24 (RBIAS)
unnamed: C606.1, C607.1, U600.6 (VDDCR)
unnamed: R707.1, U700.24 (RBIAS)
unnamed: C706.1, C707.1, U700.6 (VDDCR)
PWR_VDD_HIGH_IN: C600.1, C603.1, C700.1, C703.1, FB600.1, FB700.1, R600.1, R601.1, R602.1, R607.1, R700.1, R705.1, R706.1, U600.9 (VDDIO), U700.9 (VDDIO); also elsewhere on the board

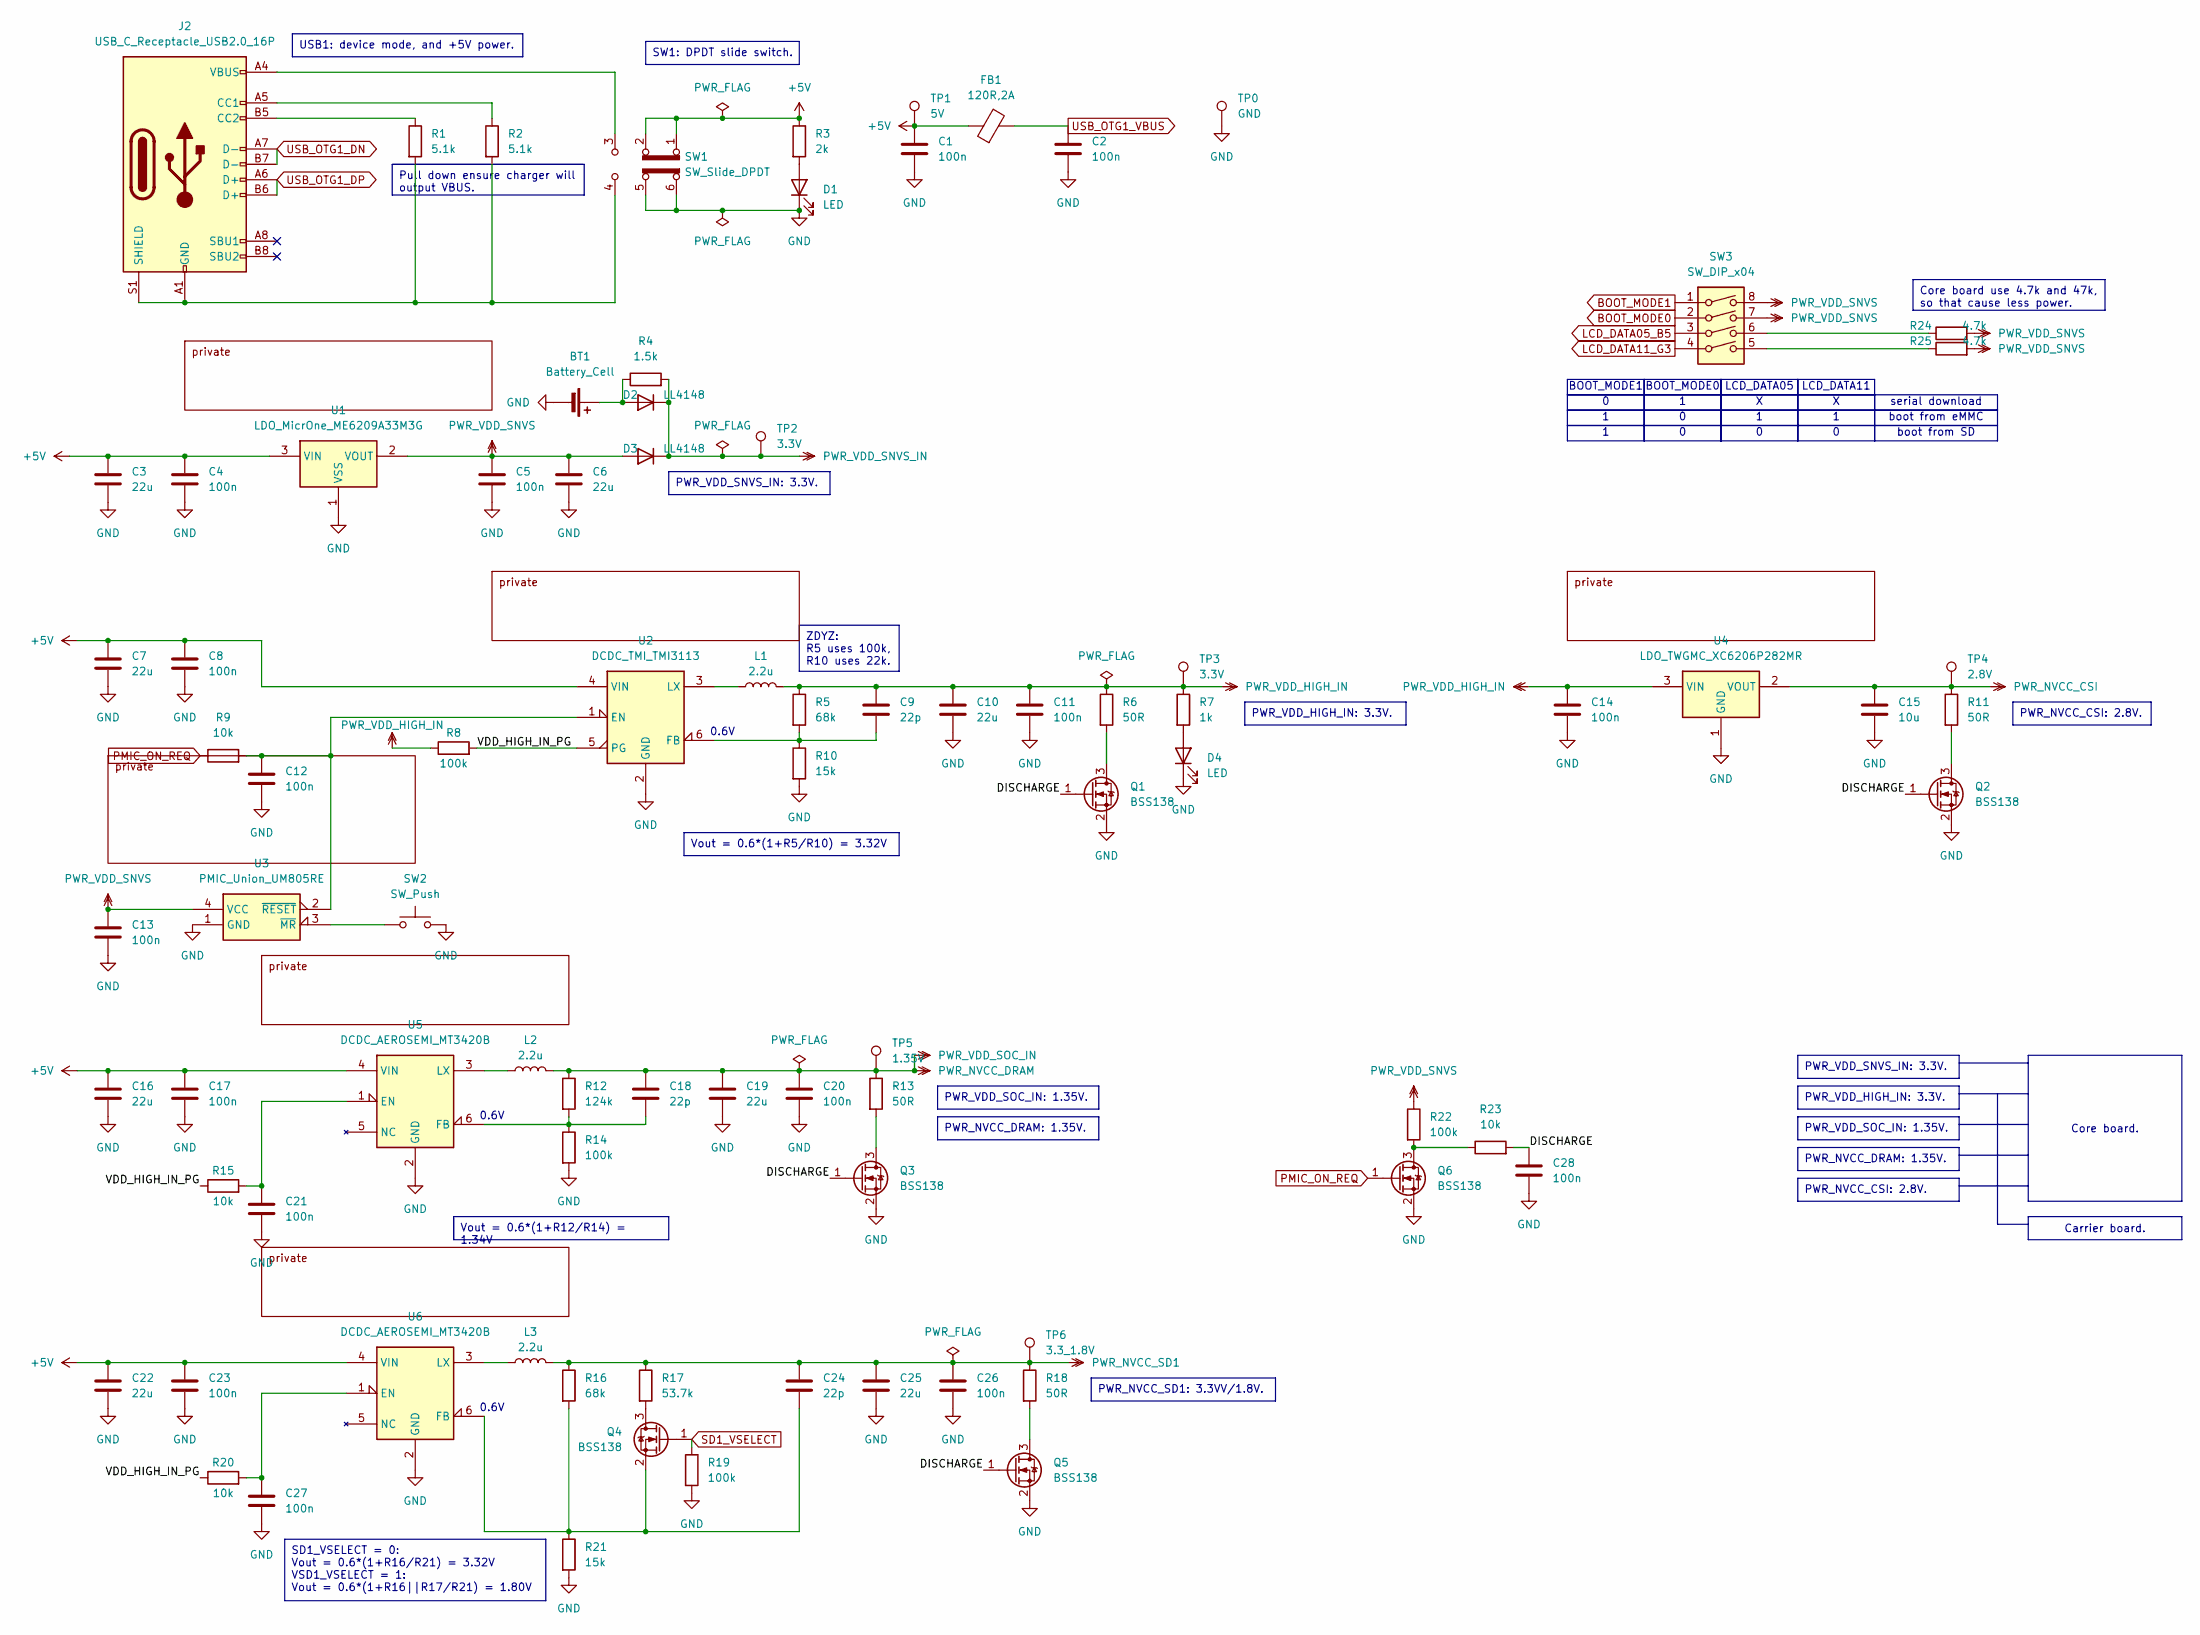
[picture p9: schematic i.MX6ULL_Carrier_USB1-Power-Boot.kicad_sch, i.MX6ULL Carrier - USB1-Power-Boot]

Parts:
BT1: Battery_Cell; Battery_CR1220_SMD
C1, C2, C4, C5, C8, C11, C12, C13, C14, C17, C20, C21, C23, C26, C27, C28: 100n; C_0603_1608Metric
C3, C6, C7, C10, C16, C19, C22, C25: 22u; C_1206_3216Metric
C9, C18, C24: 22p; C_0603_1608Metric
C15: 10u; C_0603_1608Metric
D1, D4: LED; LED_1206_3216Metric
D2, D3: LL4148; D_MiniMELF
FB1: 120R,2A; L_0603_1608Metric
J2: USB_C_Receptacle_USB2.0_16P; USB_C_Receptacle_G-Switch_GT-USB-7010ASV
L1, L2, L3: 2.2u; L_Changjiang_FNR3015S
Q1, Q2, Q3, Q4, Q5, Q6: BSS138; SOT-23-3
R1, R2: 5.1k; R_1206_3216Metric
R3: 2k; R_1206_3216Metric
R4: 1.5k; R_0603_1608Metric
R5, R16: 68k; R_0603_1608Metric
R6, R11, R13, R18: 50R; R_0603_1608Metric
R7: 1k; R_1206_3216Metric
R8, R14, R19, R22: 100k; R_0603_1608Metric
R9, R15, R20, R23: 10k; R_0603_1608Metric
R10, R21: 15k; R_0603_1608Metric
R12: 124k; R_0603_1608Metric
R17: 53.7k; R_0603_1608Metric
R24, R25: 4.7k; R_0603_1608Metric
SW1: SW_Slide_DPDT; SW_CK_JS202011CQN_DPDT_Straight
SW2: SW_Push; SW_PUSH_6mm
SW3: SW_DIP_x04; SW_DIP_SPSTx04_Slide_9.78x12.34mm_W7.62mm_P2.54mm
TP0: GND; TestPoint_Bridge_Pitch2.54mm_Drill1.0mm
TP1: 5V; TestPoint_Pad_D1.0mm
TP2, TP3: 3.3V; TestPoint_Pad_D1.0mm
TP4: 2.8V; TestPoint_Pad_D1.0mm
TP5: 1.35V; TestPoint_Pad_D1.0mm
TP6: 3.3_1.8V; TestPoint_Pad_D1.0mm
U1: LDO_MicrOne_ME6209A33M3G; SOT-23-3
U2: DCDC_TMI_TMI3113; SOT-23-6
U3: PMIC_Union_UM805RE; SOT-143
U4: LDO_TWGMC_XC6206P282MR; SOT-23-3
U5, U6: DCDC_AEROSEMI_MT3420B; SOT-23-6

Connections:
+5V: C1.1, C3.1, C4.1, C7.1, C8.1, C16.1, C17.1, C22.1, C23.1, FB1.1, R3.1, SW1.1 (A), SW1.2 (B), TP1.1, U1.3 (VIN), U2.4 (VIN), U5.4 (VIN), U6.4 (VIN); also elsewhere on the board
/USB1-Power-Boot/DISCHARGE: C28.1, Q1.1 (G), Q2.1 (G), Q3.1 (G), Q5.1 (G), R23.2
/USB1-Power-Boot/VDD_HIGH_IN_PG: R8.2, R15.1, R20.1, U2.5 (PG)
BOOT_MODE0: SW3.2; also elsewhere on the board
BOOT_MODE1: SW3.1; also elsewhere on the board
GND: BT1.2 (-), C1.2, C2.2, C3.2, C4.2, C5.2, C6.2, C7.2, C8.2, C10.2, C11.2, C12.2, C13.2, C14.2, C15.2, C16.2, C17.2, C19.2, C20.2, C21.2, C22.2, C23.2, C25.2, C26.2, C27.2, C28.2, D1.1 (K), D4.1 (K), Q1.2 (S), Q2.2 (S), Q3.2 (S), Q5.2 (S), Q6.2 (S), R10.2, R14.2, R19.2, R21.2, SW1.5 (B), SW1.6 (C), SW2.2, TP0.1, U1.1 (VSS), U2.2 (GND), U3.1 (GND), U4.1 (GND), U5.2 (GND), U6.2 (GND); also elsewhere on the board
LCD_DATA05_B5: SW3.3; also elsewhere on the board
LCD_DATA11_G3: SW3.4; also elsewhere on the board
unnamed: BT1.1 (+), D2.2 (A), R4.1
unnamed: D1.2 (A), R3.2
unnamed: D4.2 (A), R7.2
unnamed: J2.A5 (CC1), R2.1
unnamed: J2.B5 (CC2), R1.1
unnamed: J2.A1 (GND), J2.A12 (GND), J2.B1 (GND), J2.B12 (GND), J2.S1 (SHIELD), R1.2, R2.2, SW1.4 (A)
unnamed: J2.A4 (VBUS), J2.A9 (VBUS), J2.B4 (VBUS), J2.B9 (VBUS), SW1.3 (C)
unnamed: Q1.3 (D), R6.2
unnamed: Q2.3 (D), R11.2
unnamed: Q3.3 (D), R13.2
unnamed: Q4.3 (D), R17.2
unnamed: C24.2, Q4.2 (S), R16.2, R21.1, U6.6 (FB)
unnamed: Q5.3 (D), R18.2
unnamed: Q6.3 (D), R22.2, R23.1
unnamed: R24.1, SW3.6
unnamed: R25.1, SW3.5
unnamed: C12.1, R9.2, U2.1 (EN), U3.2 (~RESET)
unnamed: C9.2, R5.2, R10.1, U2.6 (FB)
unnamed: L1.1, U2.3 (LX)
unnamed: SW2.1, U3.3 (~MR)
unnamed: C21.1, R15.2, U5.1 (EN)
unnamed: C18.2, R12.2, R14.1, U5.6 (FB)
unnamed: L2.1, U5.3 (LX)
unnamed: C27.1, R20.2, U6.1 (EN)
unnamed: L3.1, U6.3 (LX)
PMIC_ON_REQ: Q6.1 (G), R9.1; also elsewhere on the board
PWR_NVCC_CSI: C15.1, R11.1, TP4.1, U4.2 (VOUT); also elsewhere on the board
PWR_NVCC_DRAM: C18.1, C19.1, C20.1, L2.2, R12.1, R13.1, TP5.1; also elsewhere on the board
PWR_NVCC_SD1: C24.1, C25.1, C26.1, L3.2, R16.1, R17.1, R18.1, TP6.1; also elsewhere on the board
PWR_VDD_HIGH_IN: C9.1, C10.1, C11.1, C14.1, L1.2, R5.1, R6.1, R7.1, R8.1, TP3.1, U4.3 (VIN); also elsewhere on the board
PWR_VDD_SNVS: C5.1, C6.1, C13.1, D3.2 (A), R22.1, R24.2, R25.2, SW3.7, SW3.8, U1.2 (VOUT), U3.4 (VCC)
PWR_VDD_SNVS_IN: D2.1 (K), D3.1 (K), R4.2, TP2.1; also elsewhere on the board
SD1_VSELECT: Q4.1 (G), R19.1; also elsewhere on the board
USB_OTG1_DN: J2.A7 (D-), J2.B7 (D-); also elsewhere on the board
USB_OTG1_DP: J2.A6 (D+), J2.B6 (D+); also elsewhere on the board
USB_OTG1_VBUS: C2.1, FB1.2; also elsewhere on the board

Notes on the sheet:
Pull down ensure charger will output VBUS.
ZDYZ: R5 uses 100k, R10 uses 22k.
SD1_VSELECT = 0: Vout = 0.6*(1+R16/R21) = 3.32V VSD1_VSELECT = 1: Vout = 0.6*(1+R16||R17/R21) = 1.80V
PWR_VDD_SOC_IN: 1.35V.
PWR_VDD_SNVS_IN: 3.3V.
Core board use 4.7k and 47k, so that cause less power.
PWR_NVCC_DRAM: 1.35V.
PWR_NVCC_CSI: 2.8V.
PWR_VDD_HIGH_IN: 3.3V.
Carrier board.
SW1: DPDT slide switch.
Vout = 0.6*(1+R5/R10) = 3.32V
Vout = 0.6*(1+R12/R14) = 1.34V
USB1: device mode, and +5V power.
PWR_NVCC_SD1: 3.3VV/1.8V.
Core board.
BOOT_MODE1
LCD_DATA11
serial download
0.6V
boot from SD
boot from eMMC
BOOT_MODE0
LCD_DATA05

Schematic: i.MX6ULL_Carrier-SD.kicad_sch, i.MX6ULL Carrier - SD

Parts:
C300: 100n; C_0603_1608Metric
C301: 10u; C_0603_1608Metric
FB300: 120R,2A; L_0603_1608Metric
J300: Micro_SD_Card_Det1; microSD_SHOUHAN_TFPush
R300, R301, R302, R303, R304, R305: 22R; R_0603_1608Metric

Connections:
GND: C300.2, C301.2, J300.6 (VSS), J300.10 (SHIELD); also elsewhere on the board
unnamed: J300.5 (CLK), R303.1
unnamed: J300.3 (CMD), R302.1
unnamed: J300.7 (DAT0), R304.1
unnamed: J300.8 (DAT1), R305.1
unnamed: J300.1 (DAT2), R300.1
unnamed: J300.2 (DAT3/CD), R301.1
unnamed: C301.1, FB300.2, J300.4 (VDD)
PWR_VDD_HIGH_IN: C300.1, FB300.1; also elsewhere on the board
SD1_CD: J300.9 (DET); also elsewhere on the board
SD1_CLK: R303.2; also elsewhere on the board
SD1_CMD: R302.2; also elsewhere on the board
SD1_DATA0: R304.2; also elsewhere on the board
SD1_DATA1: R305.2; also elsewhere on the board
SD1_DATA2: R300.2; also elsewhere on the board
SD1_DATA3: R301.2; also elsewhere on the board

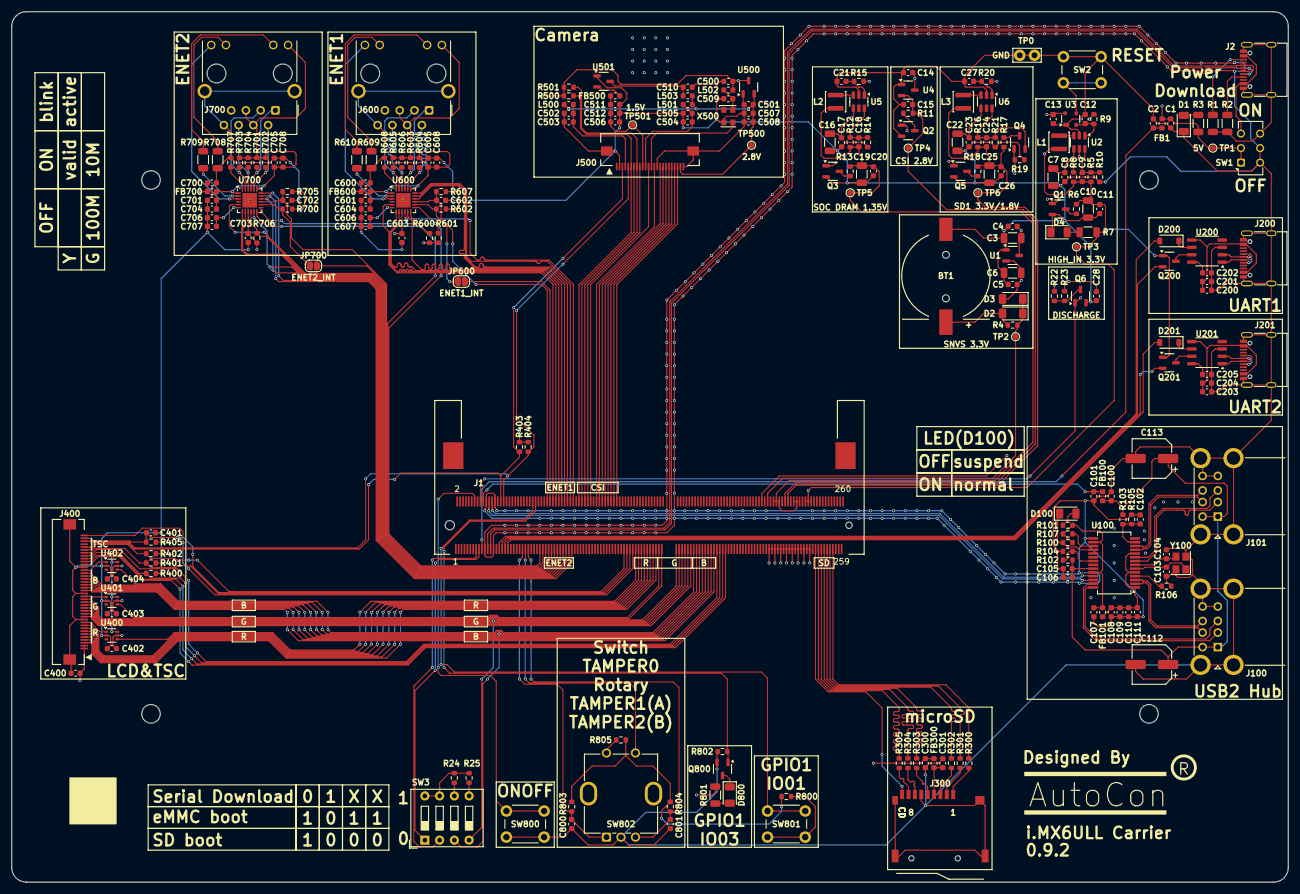
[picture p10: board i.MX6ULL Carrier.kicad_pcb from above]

Board: 4 copper layers, 220.0 x 150.0 mm, 240 parts (0 on the bottom side), 207 nets.

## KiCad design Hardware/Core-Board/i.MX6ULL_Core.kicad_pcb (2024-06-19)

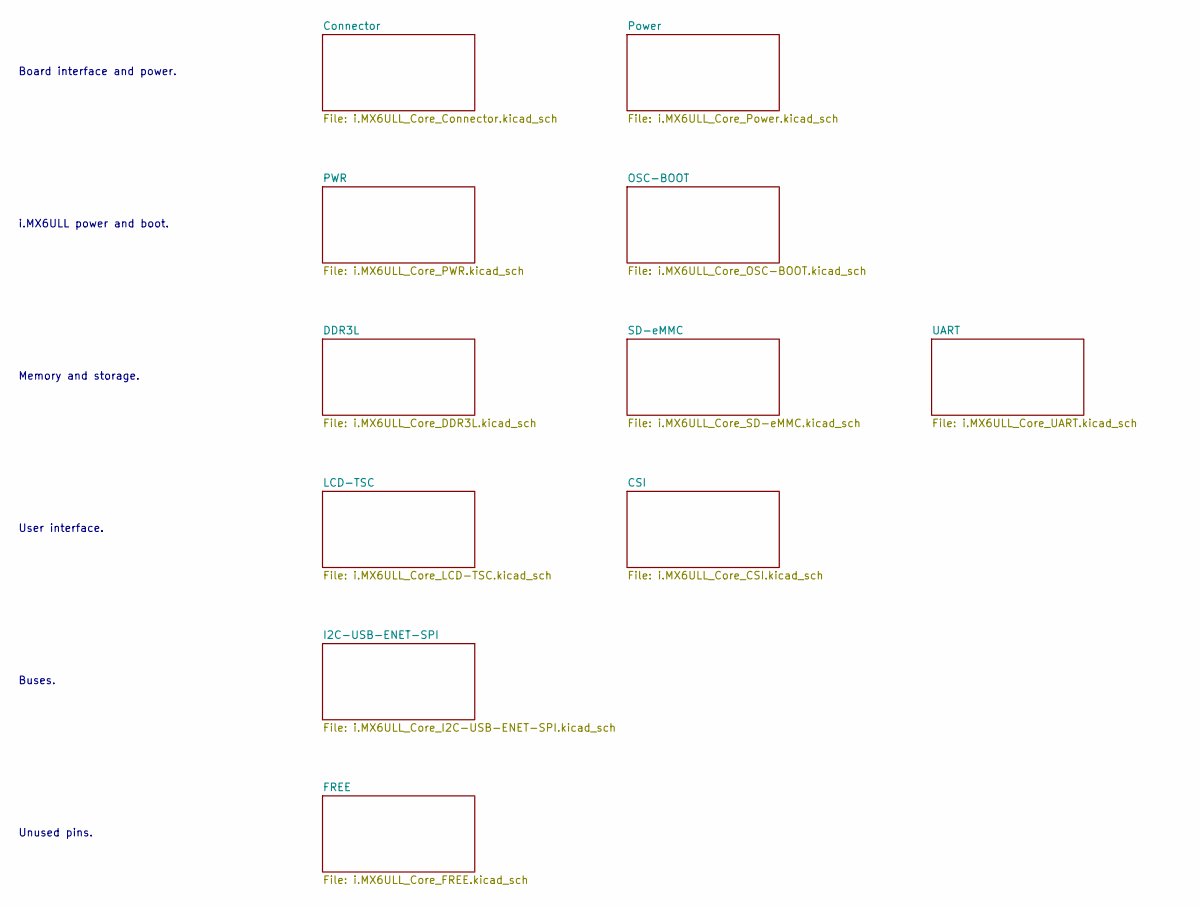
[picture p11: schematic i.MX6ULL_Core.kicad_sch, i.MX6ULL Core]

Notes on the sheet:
i.MX6ULL power and boot.
Board interface and power.
Memory and storage.
User interface.
Buses.
Unused pins.

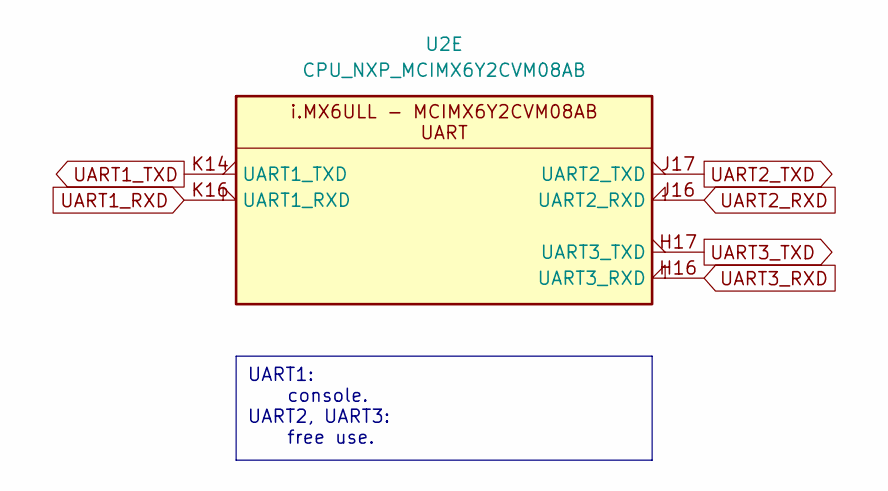
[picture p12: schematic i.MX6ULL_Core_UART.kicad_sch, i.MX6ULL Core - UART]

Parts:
U2: CPU_NXP_MCIMX6Y2CVM08AB; NXP_BGA-289_14x14mm_Layout14x14_P0.8mm_Ball0.45mm_Pad0.4mm

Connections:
UART1_RXD: U2.K16 (UART1_RXD); also elsewhere on the board
UART1_TXD: U2.K14 (UART1_TXD); also elsewhere on the board
UART2_RXD: U2.J16 (UART2_RXD); also elsewhere on the board
UART2_TXD: U2.J17 (UART2_TXD); also elsewhere on the board
UART3_RXD: U2.H16 (UART3_RXD); also elsewhere on the board
UART3_TXD: U2.H17 (UART3_TXD); also elsewhere on the board

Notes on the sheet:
UART1: console. UART2, UART3: free use.

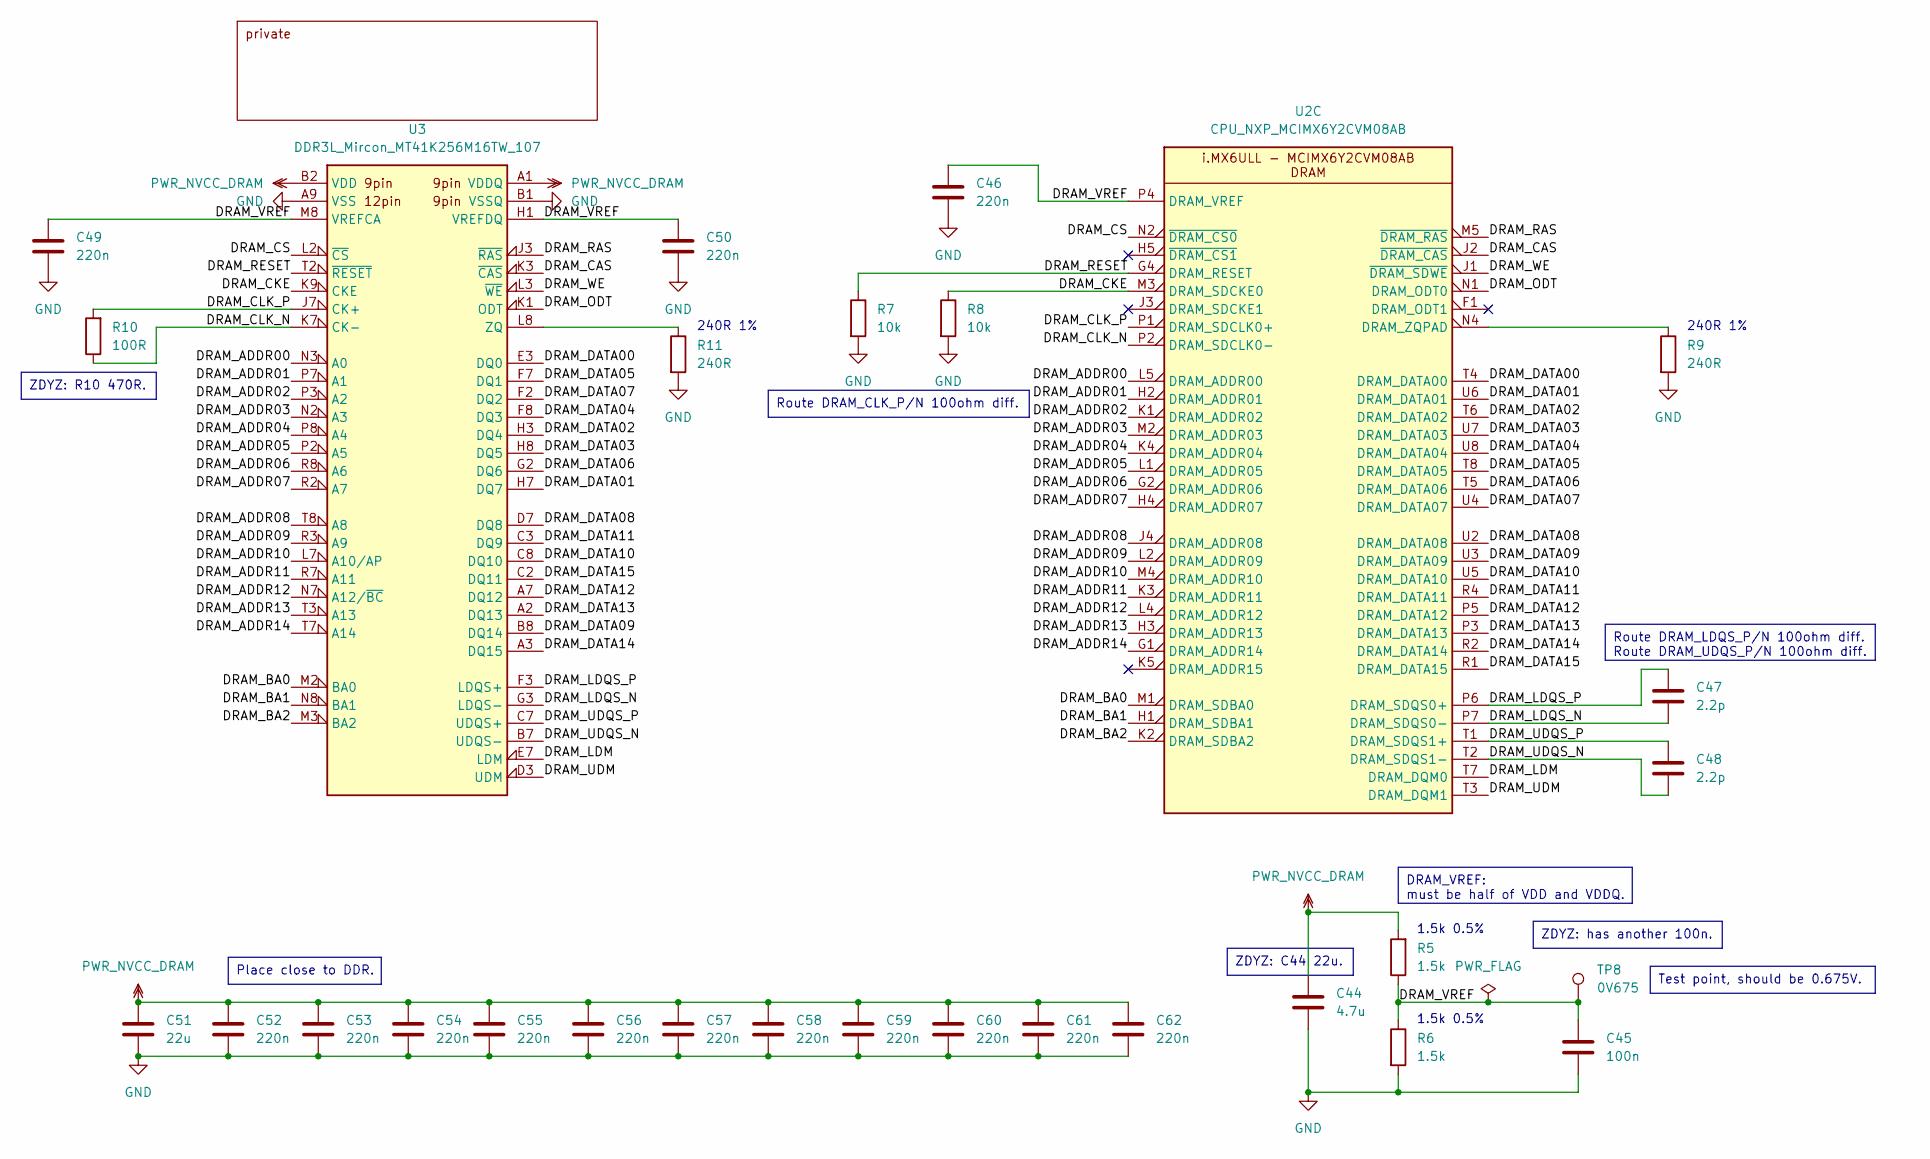
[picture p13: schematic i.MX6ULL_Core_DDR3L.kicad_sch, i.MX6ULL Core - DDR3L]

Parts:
C44: 4.7u; C_0402
C45: 100n; C_0402
C46, C49, C50, C52, C53, C54, C55, C56, C57, C58, C59, C60, C61, C62: 220n; C_0402
C47, C48: 2.2p; C_0402
C51: 22u; C_0603_1608Metric
R5, R6: 1.5k; R_0402
R7, R8: 10k; R_0402
R9, R11: 240R; R_0402
R10: 100R; R_0402
TP8: 0V675; TestPoint_Pad_D1.0mm
U2: CPU_NXP_MCIMX6Y2CVM08AB; NXP_BGA-289_14x14mm_Layout14x14_P0.8mm_Ball0.45mm_Pad0.4mm
U3: DDR3L_Mircon_MT41K256M16TW_107; Micron_FBGA-96_8x14mm_Layout9x16_P0.8mm

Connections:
/DDR3L/DRAM_ADDR00: U2.L5 (DRAM_ADDR00), U3.N3 (A0)
/DDR3L/DRAM_ADDR01: U2.H2 (DRAM_ADDR01), U3.P7 (A1)
/DDR3L/DRAM_ADDR02: U2.K1 (DRAM_ADDR02), U3.P3 (A2)
/DDR3L/DRAM_ADDR03: U2.M2 (DRAM_ADDR03), U3.N2 (A3)
/DDR3L/DRAM_ADDR04: U2.K4 (DRAM_ADDR04), U3.P8 (A4)
/DDR3L/DRAM_ADDR05: U2.L1 (DRAM_ADDR05), U3.P2 (A5)
/DDR3L/DRAM_ADDR06: U2.G2 (DRAM_ADDR06), U3.R8 (A6)
/DDR3L/DRAM_ADDR07: U2.H4 (DRAM_ADDR07), U3.R2 (A7)
/DDR3L/DRAM_ADDR08: U2.J4 (DRAM_ADDR08), U3.T8 (A8)
/DDR3L/DRAM_ADDR09: U2.L2 (DRAM_ADDR09), U3.R3 (A9)
/DDR3L/DRAM_ADDR10: U2.M4 (DRAM_ADDR10), U3.L7 (A10/AP)
/DDR3L/DRAM_ADDR11: U2.K3 (DRAM_ADDR11), U3.R7 (A11)
/DDR3L/DRAM_ADDR12: U2.L4 (DRAM_ADDR12), U3.N7 (A12/~BC)
/DDR3L/DRAM_ADDR13: U2.H3 (DRAM_ADDR13), U3.T3 (A13)
/DDR3L/DRAM_ADDR14: U2.G1 (DRAM_ADDR14), U3.T7 (A14)
/DDR3L/DRAM_BA0: U2.M1 (DRAM_SDBA0), U3.M2 (BA0)
/DDR3L/DRAM_BA1: U2.H1 (DRAM_SDBA1), U3.N8 (BA1)
/DDR3L/DRAM_BA2: U2.K2 (DRAM_SDBA2), U3.M3 (BA2)
/DDR3L/DRAM_CAS: U2.J2 (~DRAM_CAS), U3.K3 (~CAS)
/DDR3L/DRAM_CKE: R8.1, U2.M3 (DRAM_SDCKE0), U3.K9 (CKE)
/DDR3L/DRAM_CLK_N: R10.1, U2.P2 (DRAM_SDCLK0-), U3.K7 (CK-)
/DDR3L/DRAM_CLK_P: R10.2, U2.P1 (DRAM_SDCLK0+), U3.J7 (CK+)
/DDR3L/DRAM_CS: U2.N2 (~DRAM_CS0), U3.L2 (~CS)
/DDR3L/DRAM_DATA00: U2.T4 (DRAM_DATA00), U3.E3 (DQ0)
/DDR3L/DRAM_DATA01: U2.U6 (DRAM_DATA01), U3.H7 (DQ7)
/DDR3L/DRAM_DATA02: U2.T6 (DRAM_DATA02), U3.H3 (DQ4)
/DDR3L/DRAM_DATA03: U2.U7 (DRAM_DATA03), U3.H8 (DQ5)
/DDR3L/DRAM_DATA04: U2.U8 (DRAM_DATA04), U3.F8 (DQ3)
/DDR3L/DRAM_DATA05: U2.T8 (DRAM_DATA05), U3.F7 (DQ1)
/DDR3L/DRAM_DATA06: U2.T5 (DRAM_DATA06), U3.G2 (DQ6)
/DDR3L/DRAM_DATA07: U2.U4 (DRAM_DATA07), U3.F2 (DQ2)
/DDR3L/DRAM_DATA08: U2.U2 (DRAM_DATA08), U3.D7 (DQ8)
/DDR3L/DRAM_DATA09: U2.U3 (DRAM_DATA09), U3.B8 (DQ14)
/DDR3L/DRAM_DATA10: U2.U5 (DRAM_DATA10), U3.C8 (DQ10)
/DDR3L/DRAM_DATA11: U2.R4 (DRAM_DATA11), U3.C3 (DQ9)
/DDR3L/DRAM_DATA12: U2.P5 (DRAM_DATA12), U3.A7 (DQ12)
/DDR3L/DRAM_DATA13: U2.P3 (DRAM_DATA13), U3.A2 (DQ13)
/DDR3L/DRAM_DATA14: U2.R2 (DRAM_DATA14), U3.A3 (DQ15)
/DDR3L/DRAM_DATA15: U2.R1 (DRAM_DATA15), U3.C2 (DQ11)
/DDR3L/DRAM_LDM: U2.T7 (DRAM_DQM0), U3.E7 (LDM)
/DDR3L/DRAM_LDQS_N: C47.2, U2.P7 (DRAM_SDQS0-), U3.G3 (LDQS-)
/DDR3L/DRAM_LDQS_P: C47.1, U2.P6 (DRAM_SDQS0+), U3.F3 (LDQS+)
/DDR3L/DRAM_ODT: U2.N1 (DRAM_ODT0), U3.K1 (ODT)
/DDR3L/DRAM_RAS: U2.M5 (~DRAM_RAS), U3.J3 (~RAS)
/DDR3L/DRAM_RESET: R7.1, U2.G4 (DRAM_RESET), U3.T2 (~RESET)
/DDR3L/DRAM_UDM: U2.T3 (DRAM_DQM1), U3.D3 (UDM)
/DDR3L/DRAM_UDQS_N: C48.2, U2.T2 (DRAM_SDQS1-), U3.B7 (UDQS-)
/DDR3L/DRAM_UDQS_P: C48.1, U2.T1 (DRAM_SDQS1+), U3.C7 (UDQS+)
/DDR3L/DRAM_VREF: C45.1, C46.1, C49.1, C50.1, R5.1, R6.1, TP8.1, U2.P4 (DRAM_VREF), U3.H1 (VREFDQ), U3.M8 (VREFCA)
/DDR3L/DRAM_WE: U2.J1 (~DRAM_SDWE), U3.L3 (~WE)
GND: C44.2, C45.2, C46.2, C49.2, C50.2, C51.2, C52.2, C53.2, C54.2, C55.2, C56.2, C57.2, C58.2, C59.2, C60.2, C61.2, C62.2, R6.2, R7.2, R8.2, R9.2, R11.2, U3.A9 (VSS), U3.B1 (VSSQ), U3.B3 (VSS), U3.B9 (VSSQ), U3.D1 (VSSQ), U3.D8 (VSSQ), U3.E1 (VSS), U3.E2 (VSSQ), U3.E8 (VSSQ), U3.F9 (VSSQ), U3.G1 (VSSQ), U3.G8 (VSS), U3.G9 (VSSQ), U3.J2 (VSS), U3.J8 (VSS), U3.M1 (VSS), U3.M9 (VSS), U3.P1 (VSS), U3.P9 (VSS), U3.T1 (VSS), U3.T9 (VSS); also elsewhere on the board
unnamed: R9.1, U2.N4 (DRAM_ZQPAD)
unnamed: R11.1, U3.L8 (ZQ)
PWR_NVCC_DRAM: C44.1, C51.1, C52.1, C53.1, C54.1, C55.1, C56.1, C57.1, C58.1, C59.1, C60.1, C61.1, C62.1, R5.2, U3.A1 (VDDQ), U3.A8 (VDDQ), U3.B2 (VDD), U3.C1 (VDDQ), U3.C9 (VDDQ), U3.D2 (VDDQ), U3.D9 (VDD), U3.E9 (VDDQ), U3.F1 (VDDQ), U3.G7 (VDD), U3.H2 (VDDQ), U3.H9 (VDDQ), U3.K2 (VDD), U3.K8 (VDD), U3.N1 (VDD), U3.N9 (VDD), U3.R1 (VDD), U3.R9 (VDD); also elsewhere on the board

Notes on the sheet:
Test point, should be 0.675V.
Route DRAM_CLK_P/N 100ohm diff.
ZDYZ: R10 470R.
DRAM_VREF: must be half of VDD and VDDQ.
ZDYZ: C44 22u.
Route DRAM_LDQS_P/N 100ohm diff. Route DRAM_UDQS_P/N 100ohm diff.
ZDYZ: has another 100n.
Place close to DDR.
1.5k 0.5%
240R 1%


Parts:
U2: CPU_NXP_MCIMX6Y2CVM08AB; NXP_BGA-289_14x14mm_Layout14x14_P0.8mm_Ball0.45mm_Pad0.4mm

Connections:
CSI_DATA00: U2.E4 (CSI_DATA00); also elsewhere on the board
CSI_DATA01: U2.E3 (CSI_DATA01); also elsewhere on the board
CSI_DATA02: U2.E2 (CSI_DATA02); also elsewhere on the board
CSI_DATA03: U2.E1 (CSI_DATA03); also elsewhere on the board
CSI_DATA04: U2.D4 (CSI_DATA04); also elsewhere on the board
CSI_DATA05: U2.D3 (CSI_DATA05); also elsewhere on the board
CSI_DATA06: U2.D2 (CSI_DATA06); also elsewhere on the board
CSI_DATA07: U2.D1 (CSI_DATA07); also elsewhere on the board
CSI_HSYNC: U2.F3 (CSI_HSYNC); also elsewhere on the board
CSI_MCLK: U2.F5 (CSI_MCLK); also elsewhere on the board
CSI_PIXCLK: U2.E5 (CSI_PIXCLK); also elsewhere on the board
CSI_PWDN: U2.M16 (GPIO1_IO04); also elsewhere on the board
CSI_RESET: U2.K15 (~UART1_CTS/GPIO1_IO18); also elsewhere on the board
CSI_VSYNC: U2.F2 (CSI_VSYNC); also elsewhere on the board

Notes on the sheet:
ZDYZ: use GPIO1_IO02 (L14) for CSI_RESET.

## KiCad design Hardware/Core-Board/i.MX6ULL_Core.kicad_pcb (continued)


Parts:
C1, C3, C6, C7, C9, C10, C11, C12, C13, C14, C15, C16, C17, C18, C19, C20, C21, C22, C23, C25, C27, C29, C30, C31, C33, C34, C35, C37: 220n; C_0402
C2, C5: 4.7u; C_0402
C4, C28, C32: 22u; C_0402
C8, C24, C26, C36: 10u; C_0402
TP7: 2V5; TestPoint_Pad_D1.0mm
U2: CPU_NXP_MCIMX6Y2CVM08AB; NXP_BGA-289_14x14mm_Layout14x14_P0.8mm_Ball0.45mm_Pad0.4mm

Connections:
/PWR/VDD_HIGH_CAP: C24.2, C25.2, C35.2, TP7.1, U2.N6 (NVCC_DRAM_2P5), U2.R14 (VDD_HIGH_CAP), U2.R15 (VDD_HIGH_CAP)
GND: C1.2, C2.1, C3.1, C4.1, C5.1, C6.1, C7.2, C8.1, C9.1, C10.1, C11.1, C12.1, C13.1, C14.1, C15.1, C16.1, C17.2, C18.2, C19.2, C20.2, C21.2, C22.2, C23.1, C24.1, C25.1, C26.2, C27.2, C28.2, C29.2, C30.2, C31.2, C32.1, C33.1, C34.1, C35.1, C36.2, C37.2, U2.A1 (VSS), U2.A17 (VSS), U2.C3 (VSS), U2.C7 (VSS), U2.C11 (VSS), U2.C15 (VSS), U2.E8 (VSS), U2.E11 (VSS), U2.F6 (VSS), U2.F7 (VSS), U2.F8 (VSS), U2.F9 (VSS), U2.F10 (VSS), U2.F11 (VSS), U2.F12 (VSS), U2.G3 (VSS), U2.G5 (VSS), U2.G7 (VSS), U2.G12 (VSS), U2.G15 (VSS), U2.H7 (VSS), U2.H12 (VSS), U2.J5 (VSS), U2.J7 (VSS), U2.J12 (VSS), U2.K7 (VSS), U2.K12 (VSS), U2.L3 (VSS), U2.L7 (VSS), U2.L12 (VSS), U2.M7 (VSS), U2.M8 (VSS), U2.M9 (VSS), U2.M10 (VSS), U2.M11 (VSS), U2.M12 (NGND_KEL0), U2.N3 (VSS), U2.N5 (VSS), U2.R3 (VSS), U2.R5 (VSS), U2.R7 (VSS), U2.R11 (VSS), U2.R16 (VSS), U2.R17 (VSS), U2.T14 (VSS), U2.U1 (VSS), U2.U14 (VSS), U2.U17 (VSS); also elsewhere on the board
unnamed: C28.1, C29.1, C30.1, C31.1, U2.G8 (VDD_SOC_CAP), U2.H8 (VDD_SOC_CAP), U2.J8 (VDD_SOC_CAP), U2.J11 (VDD_SOC_CAP), U2.K8 (VDD_SOC_CAP), U2.K11 (VDD_SOC_CAP), U2.L8 (VDD_SOC_CAP), U2.L9 (VDD_SOC_CAP), U2.L10 (VDD_SOC_CAP), U2.L11 (VDD_SOC_CAP)
unnamed: C32.2, C33.2, C34.2, U2.G9 (VDD_ARM_CAP), U2.G10 (VDD_ARM_CAP), U2.G11 (VDD_ARM_CAP), U2.H11 (VDD_ARM_CAP)
unnamed: C26.1, C27.1, U2.P13 (NVCC_PLL)
unnamed: C23.2, U2.N12 (VDD_SNVS_CAP)
unnamed: C36.1, C37.1, U2.R12 (VDD_USB_CAP)
PWR_NVCC_CSI: C22.1, U2.F4 (NVCC_CSI); also elsewhere on the board
PWR_NVCC_DRAM: C8.2, C9.2, C10.2, C11.2, C12.2, C13.2, C14.2, U2.G6 (NVCC_DRAM), U2.H6 (NVCC_DRAM), U2.J6 (NVCC_DRAM), U2.K6 (NVCC_DRAM), U2.L6 (NVCC_DRAM), U2.M6 (NVCC_DRAM); also elsewhere on the board
PWR_NVCC_SD1: C21.1, U2.C4 (NVCC_SD1); also elsewhere on the board
PWR_VDD_HIGH_IN: C2.2, C3.2, C15.2, C16.2, C17.1, C18.1, C19.1, C20.1, U2.E7 (NVCC_NAND), U2.E13 (NVCC_LCD), U2.F13 (NVCC_ENET), U2.H13 (NVCC_UART), U2.J13 (NVCC_GPIO), U2.L13 (VDDA_ADC_3P3), U2.M13 (ADC_VREFH), U2.N13 (VDD_HIGH_IN); also elsewhere on the board
PWR_VDD_SNVS_IN: C1.1, U2.P12 (VDD_SNVS_IN); also elsewhere on the board
PWR_VDD_SOC_IN: C4.2, C5.2, C6.2, C7.1, U2.H9 (VDD_SOC_IN), U2.H10 (VDD_SOC_IN), U2.J9 (VDD_SOC_IN), U2.J10 (VDD_SOC_IN), U2.K9 (VDD_SOC_IN), U2.K10 (VDD_SOC_IN); also elsewhere on the board

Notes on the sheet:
ZDYZ: 22u+10u+100n.
NVCC_DRAM_2P5: 2.5V, Board-level connection to VDD_HIGH_CAP.
ZDYZ: C15 100n.
ZDYZ: C22 100n.
ZDYZ: C21 100n.
VDD_SNVS_CAP: Do not connect any loads. VDD_ARM_CAP: Do not connect any loads. NVCC_PLL: Do not connect any loads. VDD_USB_CAP: Do not connect any loads. VDD_HIGH_CAP: Restricted to MX6ULL loads.
ZDYZ: C2 10u.
ZDYZ: NVCC_NAND 100n.
ZDYZ: 22u+200n.
ZDYZ: 22u+100n.
Place 22u and one of 220n next to the ball L10. Place others within 50mils of via.
Place 22u and one of 220n next to the ball G9. Place others within 50mils of via.
ZDYZ: C8 22u.
Test point, should be 2.5V.


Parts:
U2: CPU_NXP_MCIMX6Y2CVM08AB; NXP_BGA-289_14x14mm_Layout14x14_P0.8mm_Ball0.45mm_Pad0.4mm

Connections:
GPIO1_IO01: U2.L15 (GPIO1_IO01); also elsewhere on the board
GPIO1_IO03: U2.L17 (GPIO1_IO03); also elsewhere on the board
SNVS_TAMPER0: U2.R10 (SNVS_TAMPER0); also elsewhere on the board
SNVS_TAMPER1: U2.R9 (SNVS_TAMPER1); also elsewhere on the board
SNVS_TAMPER2: U2.P11 (SNVS_TAMPER2); also elsewhere on the board
SNVS_TAMPER3: U2.P10 (SNVS_TAMPER3); also elsewhere on the board
SNVS_TAMPER4: U2.P9 (SNVS_TAMPER4); also elsewhere on the board
SNVS_TAMPER5: U2.N8 (SNVS_TAMPER5); also elsewhere on the board
SNVS_TAMPER6: U2.N11 (SNVS_TAMPER6); also elsewhere on the board
SNVS_TAMPER7: U2.N10 (SNVS_TAMPER7); also elsewhere on the board
SNVS_TAMPER8: U2.N9 (SNVS_TAMPER8); also elsewhere on the board
SNVS_TAMPER9: U2.R6 (SNVS_TAMPER9); also elsewhere on the board

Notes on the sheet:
ZDYZ: use GPIO1_IO01 (L15) for other modules. use GPIO1_IO03 (L17) for LED0.


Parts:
C63, C65, C68: 10u; C_0402
C64, C66, C67, C69, C70, C71: 100n; C_0402
R12, R13, R14, R15: 22R; R_0402
R16, R17, R18, R19, R20: 10k; R_0402
U2: CPU_NXP_MCIMX6Y2CVM08AB; NXP_BGA-289_14x14mm_Layout14x14_P0.8mm_Ball0.45mm_Pad0.4mm
U4: eMMC_Samsung_KLM8G1GETF-B041; Samsung_BGA-153_11.5x13mm_Layout11.5x13_P0.5mm_Ball0.3mm_Pa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

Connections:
/SD-eMMC/SD2_CLK: R14.1, U4.M6 (CLK)
/SD-eMMC/SD2_CMD: R15.1, R18.1, U4.M5 (CMD)
/SD-eMMC/SD2_DATA0: R19.1, U2.D7 (NAND_DATA00/SD2_DATA0), U4.A3 (DATA0)
/SD-eMMC/SD2_DATA1: U2.B7 (NAND_DATA01/SD2_DATA1), U4.A4 (DATA1)
/SD-eMMC/SD2_DATA2: U2.A7 (NAND_DATA02/SD2_DATA2), U4.A5 (DATA2)
/SD-eMMC/SD2_DATA3: U2.D6 (NAND_DATA03/SD2_DATA3), U4.B2 (DATA3)
/SD-eMMC/SD2_DATA4: U2.C6 (NAND_DATA04/SD2_DATA4), U4.B3 (DATA4)
/SD-eMMC/SD2_DATA5: U2.B6 (NAND_DATA05/SD2_DATA5), U4.B4 (DATA5)
/SD-eMMC/SD2_DATA6: U2.A6 (NAND_DATA06/SD2_DATA6), U4.B5 (DATA6)
/SD-eMMC/SD2_DATA7: U2.A5 (NAND_DATA07/SD2_DATA7), U4.B6 (DATA7)
/SD-eMMC/SD2_RESET: R20.1, U2.B4 (NAND_ALE/SD2_RESET), U4.K5 (~RESET)
GND: C63.2, C64.2, C65.2, C66.2, C67.2, C68.2, C69.2, C70.2, C71.2, R20.2, U4.A6 (VSS), U4.C4 (VSS), U4.E7 (VSS), U4.G5 (VSS), U4.H10 (VSS), U4.J5 (VSS), U4.K8 (VSS), U4.N2 (VSS), U4.N5 (VSS), U4.P4 (VSS), U4.P6 (VSS); also elsewhere on the board
unnamed: R12.1, U2.C1 (SD1_CLK)
unnamed: R13.1, U2.C2 (SD1_CMD)
unnamed: R14.2, U2.D8 (~NAND_RE/SD2_CLK)
unnamed: R15.2, U2.C8 (~NAND_WE/SD2_CMD)
unnamed: C63.1, C64.1, U4.C2 (VDDI)
PWR_NVCC_SD1: R16.1, R17.2; also elsewhere on the board
PWR_VDD_HIGH_IN: C65.1, C66.1, C67.1, C68.1, C69.1, C70.1, C71.1, R18.2, R19.2, U4.C6 (VCCQ), U4.E6 (VCC), U4.F5 (VCC), U4.J10 (VCC), U4.K9 (VCC), U4.M4 (VCCQ), U4.N4 (VCCQ), U4.P3 (VCCQ), U4.P5 (VCCQ); also elsewhere on the board
SD1_CD: U2.J14 (~UART1_RTS/~SD1_CD); also elsewhere on the board
SD1_CLK: R12.2; also elsewhere on the board
SD1_CMD: R13.2, R16.2; also elsewhere on the board
SD1_DATA0: R17.1, U2.B3 (SD1_DATA0); also elsewhere on the board
SD1_DATA1: U2.B2 (SD1_DATA1); also elsewhere on the board
SD1_DATA2: U2.B1 (SD1_DATA2); also elsewhere on the board
SD1_DATA3: U2.A2 (SD1_DATA3); also elsewhere on the board
SD1_VSELECT: U2.M17 (GPIO1_IO05/SD1_VSELECT); also elsewhere on the board

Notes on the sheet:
for VCC.
ZDYZ: only has R12 10R.
for VCCQ.
ZDYZ: R14 R15 uses 10R.


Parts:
C38, C39: 18p; C_0402
C40, C41: 7p; C_0402
C42, C43: 100n; C_0402
R2: 1M; R_0402
R3: 2.2M; R_0402
R4: 4.7k; R_0402
R50, R51, R52, R53, R54, R55, R56, R57, R58, R59, R60, R61, R62, R63, R64, R65, R66, R67, R68, R69, R70, R71, R72, R73: 47k; R_0402
U1: PMIC_UMW_MAX809R; SOT_23
U2: CPU_NXP_MCIMX6Y2CVM08AB; NXP_BGA-289_14x14mm_Layout14x14_P0.8mm_Ball0.45mm_Pad0.4mm
Y1: 24M; Crystal_SMD_3225-4Pin_3.2x2.5mm
Y2: 32.768k; Crystal_SMD_3215-2Pin_3.2x1.5mm

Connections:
BOOT_MODE0: U2.T10 (BOOT_MODE0); also elsewhere on the board
BOOT_MODE1: U2.U10 (BOOT_MODE1); also elsewhere on the board
GND: C38.1, C39.2, C40.1, C41.2, C42.2, C43.1, R3.1, R50.1, R51.1, R52.1, R53.1, R54.1, R55.1, R56.1, R57.1, R58.1, R59.1, R60.1, R61.1, R62.1, R63.1, R64.1, R65.1, R66.1, R67.1, R68.1, R69.1, R70.1, R71.1, R72.1, R73.1, U1.1 (GND), Y1.2, Y1.4; also elsewhere on the board
LCD_DATA00_B0: R50.2; also elsewhere on the board
LCD_DATA01_B1: R51.2; also elsewhere on the board
LCD_DATA02_B2: R52.2; also elsewhere on the board
LCD_DATA03_B3: R53.2; also elsewhere on the board
LCD_DATA04_B4: R54.2; also elsewhere on the board
LCD_DATA05_B5: R55.2; also elsewhere on the board
LCD_DATA06_B6: R4.2, R56.2; also elsewhere on the board
LCD_DATA07_B7: R57.2; also elsewhere on the board
LCD_DATA08_G0: R58.2; also elsewhere on the board
LCD_DATA09_G1: R59.2; also elsewhere on the board
LCD_DATA10_G2: R60.2; also elsewhere on the board
LCD_DATA11_G3: R61.2; also elsewhere on the board
LCD_DATA12_G4: R62.2; also elsewhere on the board
LCD_DATA13_G5: R63.2; also elsewhere on the board
LCD_DATA14_G6: R64.2; also elsewhere on the board
LCD_DATA15_G7: R65.2; also elsewhere on the board
LCD_DATA16_R0: R66.2; also elsewhere on the board
LCD_DATA17_R1: R67.2; also elsewhere on the board
LCD_DATA18_R2: R68.2; also elsewhere on the board
LCD_DATA19_R3: R69.2; also elsewhere on the board
LCD_DATA20_R4: R70.2; also elsewhere on the board
LCD_DATA21_R5: R71.2; also elsewhere on the board
LCD_DATA22_R6: R72.2; also elsewhere on the board
LCD_DATA23_R7: R73.2; also elsewhere on the board
unnamed: C42.1, U1.2 (~RESET), U2.P8 (~POR)
unnamed: C40.2, U2.T11 (RTC_XTALI), Y2.2
unnamed: C41.1, U2.U11 (RTC_XTALO), Y2.1
unnamed: C38.2, R2.1, R3.2, U2.T16 (XTALI), Y1.1
unnamed: C39.1, R2.2, U2.T17 (XTALO), Y1.3
ONOFF: U2.R8 (ONOFF); also elsewhere on the board
PMIC_ON_REQ: U2.T9 (SNVS_PMIC_ON_REQ); also elsewhere on the board
PMIC_STBY_REQ: U2.U9 (CCM_PMIC_STBY_REQ); also elsewhere on the board
PWR_VDD_HIGH_IN: C43.2, R4.1, U1.3 (VDD); also elsewhere on the board

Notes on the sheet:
ONOFF can be connected to a button to GND.
BOOT_MODE1/0: internal pull down 100k. 01: serial download 10: internal boot Use: connect a switch to VDD_SNVS_IN.
ZDYZ: has no R3.
BOOT_CFG1[5] <-> LCD_DATA05: pull up 4.7k to VDD_HIGH_IN to boot from eMMC or SD BOOT_CFG2[3] <-> LCD_DATA11: config SD/eMMC mount point USDHCx LCD_DATA05, LCD_DATA11: 00: boot from SD on USDHC1 11: boot from eMMC on USDHC2
Y1: 24MHz, 50ppm.
You can use 1k and 10k, but will cause more power.
BOOT_CFG1[6] <-> LCD_DATA06: pull up, boot device SD or eMMC
Maybe LCD_DATA06 can be only pulled up.
PMIC_STBY_REQ output to external board if used, or left unconnected.
ZDYZ: C40 C41 use 18p.
~{POR} should be pulled down by U1 until VDD_ARM_CAP and VDD_SOC_CAP stable.
PMIC_ON_REQ should output to external board.
C38,C39,C40,C41: 100k ESR.

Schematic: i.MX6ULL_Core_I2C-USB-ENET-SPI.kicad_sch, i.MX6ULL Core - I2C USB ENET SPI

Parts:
C72, C73: 1u; C_0402
R22, R23: 10R; R_0402
U2: CPU_NXP_MCIMX6Y2CVM08AB; NXP_BGA-289_14x14mm_Layout14x14_P0.8mm_Ball0.45mm_Pad0.4mm

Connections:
ECSPI3_MISO: U2.A4 (ECSPI3_MISO/NAND_CLE); also elsewhere on the board
ECSPI3_MOSI: U2.B5 (ECSPI3_MOSI/~NAND_CE1); also elsewhere on the board
ECSPI3_SCLK: U2.C5 (ECSPI3_SCLK/~NAND_CE0); also elsewhere on the board
ECSPI3_SS0: U2.A3 (ECSPI3_SS0/~NAND_READY); also elsewhere on the board
ENET1_INT: U2.G14 (GOIO1_IO27/~UART3_RTS); also elsewhere on the board
ENET1_RESET: U2.H14 (GPIO1_IO23/~UART2_RTS); also elsewhere on the board
ENET1_RX_DATA0: U2.F16 (ENET1_RX_DATA0); also elsewhere on the board
ENET1_RX_DATA1: U2.E17 (ENET1_RX_DATA1); also elsewhere on the board
ENET1_RX_EN: U2.E16 (ENET1_RX_EN); also elsewhere on the board
ENET1_RX_ER: U2.D15 (ENET1_RX_ER); also elsewhere on the board
ENET1_TX_CLK: R22.1; also elsewhere on the board
ENET1_TX_DATA0: U2.E15 (ENET1_TX_DATA0); also elsewhere on the board
ENET1_TX_DATA1: U2.E14 (ENET1_TX_DATA1); also elsewhere on the board
ENET1_TX_EN: U2.F15 (ENET1_TX_EN); also elsewhere on the board
ENET2_INT: U2.H15 (~UART3_CTS/GPIO1_IO26); also elsewhere on the board
ENET2_RESET: U2.J15 (~UART2_CTS/GPIO1_IO22); also elsewhere on the board
ENET2_RX_DATA0: U2.C17 (ENET2_RX_DATA0); also elsewhere on the board
ENET2_RX_DATA1: U2.C16 (ENET2_RX_DATA1); also elsewhere on the board
ENET2_RX_EN: U2.B17 (ENET2_RX_EN); also elsewhere on the board
ENET2_RX_ER: U2.D16 (ENET2_RX_ER); also elsewhere on the board
ENET2_TX_CLK: R23.1; also elsewhere on the board
ENET2_TX_DATA0: U2.A15 (ENET2_TX_DATA0); also elsewhere on the board
ENET2_TX_DATA1: U2.A16 (ENET2_TX_DATA1); also elsewhere on the board
ENET2_TX_EN: U2.B15 (ENET2_TX_EN); also elsewhere on the board
ENET_MDC: U2.L16 (ENET_MDC/GPIO1_IO07); also elsewhere on the board
ENET_MDIO: U2.K17 (ENET_MDIO/GPIO1_IO06); also elsewhere on the board
GND: C72.2, C73.2; also elsewhere on the board
I2C1_CLK: U2.G17 (I2C1_CLK/UART4_TXD); also elsewhere on the board
I2C1_SDA: U2.G16 (I2C1_SDA/UART4_RXD); also elsewhere on the board
I2C2_CLK: U2.F17 (UART5_TXD/I2C2_CLK); also elsewhere on the board
I2C2_SDA: U2.G13 (UART5_RXD/I2C2_SDA); also elsewhere on the board
unnamed: R22.2, U2.F14 (ENET1_TX_CLK)
unnamed: R23.2, U2.D17 (ENET2_TX_CLK)
USB_OTG1_DN: U2.T15 (USB_OTG1_DN); also elsewhere on the board
USB_OTG1_DP: U2.U15 (USB_OTG1_DP); also elsewhere on the board
USB_OTG1_ID: U2.K13 (ANATOP_OTG1_ID/GPIO1_IO00); also elsewhere on the board
USB_OTG1_VBUS: C72.1, U2.T12 (USB_OTG1_VBUS); also elsewhere on the board
USB_OTG2_DN: U2.T13 (USB_OTG2_DN); also elsewhere on the board
USB_OTG2_DP: U2.U13 (USB_OTG2_DP); also elsewhere on the board
USB_OTG2_VBUS: C73.1, U2.U12 (USB_OTG2_VBUS); also elsewhere on the board

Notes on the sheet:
ZDYZ: use SNVS_TAMPER8 (N9) for ENET2_RESET. use SNVS_TAMPER6 (N11) for ENET2_INT.
ZDYZ: C73 100n.
C72,C73: 1uF, 10V rated.
ZDYZ: C72 100n.
ZDYZ: use SNVS_TAMPER7 (N10) for ENET1_RESET. use SNVS_TAMPER5 (N8) for ENET1_INT.

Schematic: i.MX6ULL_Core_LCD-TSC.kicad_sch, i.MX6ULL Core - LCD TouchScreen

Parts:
R21: 10R; R_0402
U2: CPU_NXP_MCIMX6Y2CVM08AB; NXP_BGA-289_14x14mm_Layout14x14_P0.8mm_Ball0.45mm_Pad0.4mm

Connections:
LCD_BL_PWM: U2.N17 (GPIO1_IO08/PWM1_OUT); also elsewhere on the board
LCD_CLK: R21.1; also elsewhere on the board
LCD_DATA00_B0: U2.B9 (LCD_DATA00); also elsewhere on the board
LCD_DATA01_B1: U2.A9 (LCD_DATA01); also elsewhere on the board
LCD_DATA02_B2: U2.E10 (LCD_DATA02); also elsewhere on the board
LCD_DATA03_B3: U2.D10 (LCD_DATA03); also elsewhere on the board
LCD_DATA04_B4: U2.C10 (LCD_DATA04); also elsewhere on the board
LCD_DATA05_B5: U2.B10 (LCD_DATA05); also elsewhere on the board
LCD_DATA06_B6: U2.A10 (LCD_DATA06); also elsewhere on the board
LCD_DATA07_B7: U2.D11 (LCD_DATA07); also elsewhere on the board
LCD_DATA08_G0: U2.B11 (LCD_DATA08); also elsewhere on the board
LCD_DATA09_G1: U2.A11 (LCD_DATA09); also elsewhere on the board
LCD_DATA10_G2: U2.E12 (LCD_DATA10); also elsewhere on the board
LCD_DATA11_G3: U2.D12 (LCD_DATA11); also elsewhere on the board
LCD_DATA12_G4: U2.C12 (LCD_DATA12); also elsewhere on the board
LCD_DATA13_G5: U2.B12 (LCD_DATA13); also elsewhere on the board
LCD_DATA14_G6: U2.A12 (LCD_DATA14); also elsewhere on the board
LCD_DATA15_G7: U2.D13 (LCD_DATA15); also elsewhere on the board
LCD_DATA16_R0: U2.C13 (LCD_DATA16); also elsewhere on the board
LCD_DATA17_R1: U2.B13 (LCD_DATA17); also elsewhere on the board
LCD_DATA18_R2: U2.A13 (LCD_DATA18); also elsewhere on the board
LCD_DATA19_R3: U2.D14 (LCD_DATA19); also elsewhere on the board
LCD_DATA20_R4: U2.C14 (LCD_DATA20); also elsewhere on the board
LCD_DATA21_R5: U2.B14 (LCD_DATA21); also elsewhere on the board
LCD_DATA22_R6: U2.A14 (LCD_DATA22); also elsewhere on the board
LCD_DATA23_R7: U2.B16 (LCD_DATA23); also elsewhere on the board
LCD_ENABLE: U2.B8 (LCD_ENABLE); also elsewhere on the board
LCD_HSYNC: U2.D9 (LCD_HSYNC); also elsewhere on the board
LCD_RESET: U2.E9 (LCD_RESET); also elsewhere on the board
LCD_VSYNC: U2.C9 (LCD_VSYNC); also elsewhere on the board
unnamed: R21.2, U2.A8 (LCD_CLK)
TSC_INT: U2.M15 (GPIO1_IO09); also elsewhere on the board
TSC_RESET: U2.L14 (GPIO1_IO02); also elsewhere on the board

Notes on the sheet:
ZDYZ: use LCD_RESET (E9) for reset DCDC_3V3.
ZDYZ: use SNVS_TAMPER9 (R6) for TSC_RESET.

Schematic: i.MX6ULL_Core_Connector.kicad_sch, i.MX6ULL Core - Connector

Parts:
J1: SODIMM-260_DDR4; SODIMM-260_DDR4_Card_edge
M1, M2, M3, M4, M5, M6, M7, M8: MARK_D1.0mm

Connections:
BOOT_MODE0: J1.15; also elsewhere on the board
BOOT_MODE1: J1.17; also elsewhere on the board
CSI_DATA00: J1.106; also elsewhere on the board
CSI_DATA01: J1.110; also elsewhere on the board
CSI_DATA02: J1.112; also elsewhere on the board
CSI_DATA03: J1.108; also elsewhere on the board
CSI_DATA04: J1.104; also elsewhere on the board
CSI_DATA05: J1.100; also elsewhere on the board
CSI_DATA06: J1.98; also elsewhere on the board
CSI_DATA07: J1.94; also elsewhere on the board
CSI_HSYNC: J1.92; also elsewhere on the board
CSI_MCLK: J1.96; also elsewhere on the board
CSI_PIXCLK: J1.102; also elsewhere on the board
CSI_PWDN: J1.90; also elsewhere on the board
CSI_RESET: J1.86; also elsewhere on the board
CSI_VSYNC: J1.88; also elsewhere on the board
ECSPI3_MISO: J1.244; also elsewhere on the board
ECSPI3_MOSI: J1.242; also elsewhere on the board
ECSPI3_SCLK: J1.248; also elsewhere on the board
ECSPI3_SS0: J1.246; also elsewhere on the board
ENET1_INT: J1.66; also elsewhere on the board
ENET1_RESET: J1.64; also elsewhere on the board
ENET1_RX_DATA0: J1.72; also elsewhere on the board
ENET1_RX_DATA1: J1.70; also elsewhere on the board
ENET1_RX_EN: J1.74; also elsewhere on the board
ENET1_RX_ER: J1.82; also elsewhere on the board
ENET1_TX_CLK: J1.68; also elsewhere on the board
ENET1_TX_DATA0: J1.78; also elsewhere on the board
ENET1_TX_DATA1: J1.80; also elsewhere on the board
ENET1_TX_EN: J1.76; also elsewhere on the board
ENET2_INT: J1.65; also elsewhere on the board
ENET2_RESET: J1.63; also elsewhere on the board
ENET2_RX_DATA0: J1.71; also elsewhere on the board
ENET2_RX_DATA1: J1.73; also elsewhere on the board
ENET2_RX_EN: J1.75; also elsewhere on the board
ENET2_RX_ER: J1.69; also elsewhere on the board
ENET2_TX_CLK: J1.67; also elsewhere on the board
ENET2_TX_DATA0: J1.81; also elsewhere on the board
ENET2_TX_DATA1: J1.79; also elsewhere on the board
ENET2_TX_EN: J1.77; also elsewhere on the board
ENET_MDC: J1.59; also elsewhere on the board
ENET_MDIO: J1.61; also elsewhere on the board
GND: J1.21, J1.22, J1.27, J1.28, J1.207, J1.209, J1.211, J1.213, J1.215, J1.217, J1.219, J1.221, J1.223, J1.225, J1.227, J1.229, J1.231, J1.233, J1.235, J1.237; also elsewhere on the board
GPIO1_IO01: J1.54; also elsewhere on the board
GPIO1_IO03: J1.56; also elsewhere on the board
I2C1_CLK: J1.34; also elsewhere on the board
I2C1_SDA: J1.32; also elsewhere on the board
I2C2_CLK: J1.38; also elsewhere on the board
I2C2_SDA: J1.36; also elsewhere on the board
LCD_BL_PWM: J1.121; also elsewhere on the board
LCD_CLK: J1.179; also elsewhere on the board
LCD_DATA00_B0: J1.171; also elsewhere on the board
LCD_DATA01_B1: J1.169; also elsewhere on the board
LCD_DATA02_B2: J1.167; also elsewhere on the board
LCD_DATA03_B3: J1.165; also elsewhere on the board
LCD_DATA04_B4: J1.163; also elsewhere on the board
LCD_DATA05_B5: J1.161; also elsewhere on the board
LCD_DATA06_B6: J1.159; also elsewhere on the board
LCD_DATA07_B7: J1.157; also elsewhere on the board
LCD_DATA08_G0: J1.155; also elsewhere on the board
LCD_DATA09_G1: J1.153; also elsewhere on the board
LCD_DATA10_G2: J1.151; also elsewhere on the board
LCD_DATA11_G3: J1.149; also elsewhere on the board
LCD_DATA12_G4: J1.147; also elsewhere on the board
LCD_DATA13_G5: J1.145; also elsewhere on the board
LCD_DATA14_G6: J1.143; also elsewhere on the board
LCD_DATA15_G7: J1.141; also elsewhere on the board
LCD_DATA16_R0: J1.139; also elsewhere on the board
LCD_DATA17_R1: J1.137; also elsewhere on the board
LCD_DATA18_R2: J1.135; also elsewhere on the board
LCD_DATA19_R3: J1.133; also elsewhere on the board
LCD_DATA20_R4: J1.131; also elsewhere on the board
LCD_DATA21_R5: J1.129; also elsewhere on the board
LCD_DATA22_R6: J1.127; also elsewhere on the board
LCD_DATA23_R7: J1.125; also elsewhere on the board
LCD_ENABLE: J1.173; also elsewhere on the board
LCD_HSYNC: J1.177; also elsewhere on the board
LCD_RESET: J1.123; also elsewhere on the board
LCD_VSYNC: J1.175; also elsewhere on the board
ONOFF: J1.14; also elsewhere on the board
PMIC_ON_REQ: J1.18; also elsewhere on the board
PMIC_STBY_REQ: J1.16; also elsewhere on the board
PWR_NVCC_CSI: J1.220; also elsewhere on the board
PWR_NVCC_DRAM: J1.226, J1.228, J1.230; also elsewhere on the board
PWR_NVCC_SD1: J1.222; also elsewhere on the board
PWR_VDD_HIGH_IN: J1.234, J1.236, J1.238; also elsewhere on the board
PWR_VDD_SNVS_IN: J1.208; also elsewhere on the board
PWR_VDD_SOC_IN: J1.212, J1.214, J1.216; also elsewhere on the board
SD1_CD: J1.241; also elsewhere on the board
SD1_CLK: J1.247; also elsewhere on the board
SD1_CMD: J1.249; also elsewhere on the board
SD1_DATA0: J1.245; also elsewhere on the board
SD1_DATA1: J1.243; also elsewhere on the board
SD1_DATA2: J1.253; also elsewhere on the board
SD1_DATA3: J1.251; also elsewhere on the board
SD1_VSELECT: J1.204; also elsewhere on the board
SNVS_TAMPER0: J1.49; also elsewhere on the board
SNVS_TAMPER1: J1.47; also elsewhere on the board
SNVS_TAMPER2: J1.51; also elsewhere on the board
SNVS_TAMPER3: J1.46; also elsewhere on the board
SNVS_TAMPER4: J1.44; also elsewhere on the board
SNVS_TAMPER5: J1.42; also elsewhere on the board
SNVS_TAMPER6: J1.50; also elsewhere on the board
SNVS_TAMPER7: J1.48; also elsewhere on the board
SNVS_TAMPER8: J1.52; also elsewhere on the board
SNVS_TAMPER9: J1.45; also elsewhere on the board
TSC_INT: J1.119; also elsewhere on the board
TSC_RESET: J1.117; also elsewhere on the board
UART1_RXD: J1.31; also elsewhere on the board
UART1_TXD: J1.33; also elsewhere on the board
UART2_RXD: J1.37; also elsewhere on the board
UART2_TXD: J1.35; also elsewhere on the board
UART3_RXD: J1.41; also elsewhere on the board
UART3_TXD: J1.39; also elsewhere on the board
USB_OTG1_DN: J1.25; also elsewhere on the board
USB_OTG1_DP: J1.23; also elsewhere on the board
USB_OTG1_ID: J1.29; also elsewhere on the board
USB_OTG1_VBUS: J1.19; also elsewhere on the board
USB_OTG2_DN: J1.26; also elsewhere on the board
USB_OTG2_DP: J1.24; also elsewhere on the board
USB_OTG2_VBUS: J1.20; also elsewhere on the board

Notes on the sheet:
8 marks for SMT.

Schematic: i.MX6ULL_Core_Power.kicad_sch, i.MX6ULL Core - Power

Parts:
D1: LED; LED_0402
R1: 1k; R_0402
TP1, TP2: 3V3; TestPoint_Pad_D1.0mm; not fitted
TP3, TP4: 1V35; TestPoint_Pad_D1.0mm; not fitted
TP5: 2V8; TestPoint_Pad_D1.0mm; not fitted
TP6: 3V3,1V8; TestPoint_Pad_D1.0mm; not fitted

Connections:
GND: D1.1 (K); also elsewhere on the board
unnamed: D1.2 (A), R1.1
PWR_VDD_HIGH_IN: R1.2, TP2.1; also elsewhere on the board

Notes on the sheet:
DCDC or LDO
DCDC
+5V
LDO
PWR_VDD_SNVS_IN 3.3V always on
PWR_VDD_SOC_IN 1.35V turned on by PWR_VDD_HIGH_IN
PMIC_ON_REQ
PWR_VDD_HIGH_IN 3.3V turned on by PMIC_ON_REQ
PWR_NVCC_CSI 2.8V turned on by PWR_VDD_HIGH_IN OR LDO from PWR_VDD_HIGH_IN
PWR_NVCC_SD1 3.3V/1.8V turned on by PWR_VDD_HIGH_IN controlled by SD1_VSELECT, switch voltage
PWR_NVCC_DRAM 1.35V turned on by PWR_VDD_HIGH_IN



Board: 6 copper layers, 69.6 x 33.0 mm, 138 parts (44 on the bottom side), 204 nets.

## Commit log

2024-06-19 Add board image.
2024-06-19 Add hardware.
    [i.MX6ULL Carrier.kicad_pcb, i.MX6ULL Carrier.kicad_sch, i.MX6ULL_Carrier-SD.kicad_sch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]
